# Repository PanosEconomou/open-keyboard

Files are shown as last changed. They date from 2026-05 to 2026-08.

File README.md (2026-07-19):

# open-keyboard

I want a cool keyboard, and if I am going to spend so much money on a good one that someone else makes why not spend even more money for a worse one that I make?

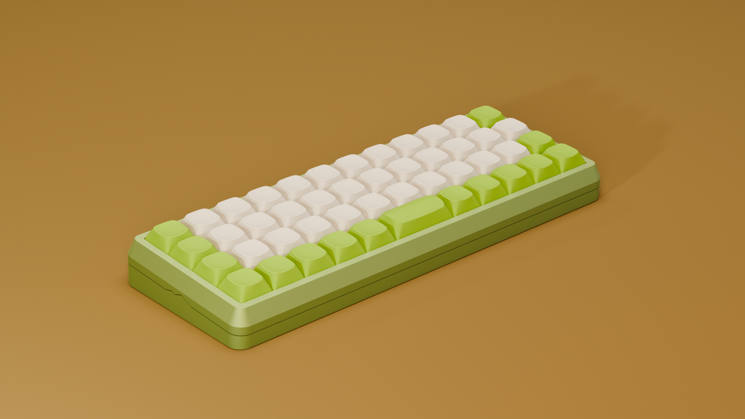
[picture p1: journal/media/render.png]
render


## Journal

There is a [journal](./journal/02-layout-framing.md) here somewhere that documents the process.

## Acknowledgements

This project uses or is inspired by a lot of open-source tools, projects, and generous people who documented their work. Thank you so much!

### Tools & Software
- [Keyboard Layout Editor](https://www.keyboard-layout-editor.com) — Ian Prest's layout design tool, used for every layout iteration
- [QMK Firmware](https://qmk.fm) — the open-source "Quantum Mechanical Keyboard" firmware
- [FreeCAD](https://www.freecad.org) — open-source CAD used for the case design
- [KiCad](https://www.kicad.org) — open-source EDA used for the schematic and PCB
- [Blender](https://www.blender.org) — used for the renders
- [Plate & Case Builder](http://builder.swillkb.com) — swillkb's tool for generating plates/cases from a layout

### Open-Source Projects & Libraries
- [cubiq/OPK](https://github.com/cubiq/OPK) — open keycap profile / library (included as a submodule)
- [CadQuery](https://github.com/CadQuery/cadquery) — Python-based parametric CAD used for keycap generation
- [ai03-2725/MX_V2](https://github.com/ai03-2725/MX_V2) — MX switch KiCad component library
- [ebastler/marbastlib](https://github.com/ebastler/marbastlib) — recent MX hotswap footprint library (the one I went with)
- [kiswitch/kiswitch](https://github.com/kiswitch/kiswitch) — switch footprint library
- [olkb/olkb_parts](https://github.com/olkb/olkb_parts) — OLKB's CAD parts, referenced for case design
- [adafruit/Adafruit-Feather-RP2040-PCB](https://github.com/adafruit/Adafruit-Feather-RP2040-PCB) — RP2040 reference design
- [Unified Daughterboard standard](https://unified-daughterboard.github.io) — daughterboard spec for the gasket-mount design
- [network2501/planck](https://github.com/network2501/planck) — long-press shift layout idea

### Guides & Articles
- [Ruiqi Mao's Keyboard PCB Guide](https://github.com/ruiqimao/keyboard-pcb-guide) — invaluable PCB walkthrough
- [The Planck Constant](http://thedarnedestthing.com/planck%20constant) — thoughtful write-up on Planck layout design
- [Evan Travers — 40% keyboard layouts](https://evantravers.com/articles/2019/04/20/community-post-40-keyboard-layouts/) — community layout roundup
- [Designing Keycaps for Fun and Profit (kbd.news)](https://kbd.news/Designing-Keycaps-for-Fun-and-Profit-1775.html) — PBS keycap creator's guide
- [RP2040 Hardware Design Guide (Raspberry Pi)](https://pip-assets.raspberrypi.com/categories/814-rp2040/documents/RP-008279-DS-1-hardware-design-with-rp2040.pdf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)
- [How to make your PCB hotswappable](https://www.reddit.com/r/MechanicalKeyboards/comments/5a399o/guide_how_to_make_your_pcb_hotswappable/)

### Community Threads & Inspiration
- [r/olkb](https://www.reddit.com/r/olkb/) and [r/MechanicalKeyboards](https://www.reddit.com/r/MechanicalKeyboards/wiki/customkeyboards/) — the wikis, guides, and countless threads
- [Detailed guide to making a custom keyboard](https://www.reddit.com/r/MechanicalKeyboards/comments/4l0p41/guide_detailed_guide_to_making_a_custom_keyboard/)
- [Default Planck layout thread](https://www.reddit.com/r/MechanicalKeyboards/comments/4vs3iz/this_is_the_default_planck_layout/) and [Planck PCB options](https://www.reddit.com/r/olkb/comments/rh9r3n/planck_pcb_options/)
- [40s keycaps — where to begin](https://www.reddit.com/r/MechanicalKeyboards/comments/dzamyl/40s_keycaps_where_to_begin/)
- [Gasket mounting discussion (geekhack)](https://geekhack.org/index.php?topic=101731.0) and [switch LED orientation (geekhack)](https://geekhack.org/index.php?topic=72713.0)
- [Planck PCB rev 6 (imgur)](https://imgur.com/a/planck-pcb-rev-6-8gn3UQs) — component-margin reference
- Geonix and YMDK Air 40 builds that got me started (linked in the README)

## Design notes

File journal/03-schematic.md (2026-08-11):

# Making the schematic

Having decided on the Planck layout there are a couple of things to consider a bout PCBs. 

- Solder or Hot swap. Turns out one doesn't have to solder switches in place if they don't want to by getting special pcbs with recepticles in them. Thing is because I haven't heard what different switches sound like and I would like to have mine be quiet, I might need to iterate on the swtitches so having to solder everything over and over again seems like a bummer. 
- Custom or kit. I would love to design one from scratch but this seems that it would take years to do hehehe. 
- Connectivity. I do want usb-C everything and given that custom keyboarding is dead as a hobby worldwide since before usb-c-ing the world it could be hard to find a nice USB. 
- Microcontroller. TURNS OUT YOU CAN DO THIS WITH A PRO MICRO?! That's awesome! I can write everything in an arduino IDE, or use qmk which apparently works.

[Here](https://www.reddit.com/r/olkb/comments/rh9r3n/planck_pcb_options/) is a thread of people talking about options for a planck pcb like 4 years ago. 
Also, [this](https://customkbd.com/collections/complete-kits/products/contra-40-keyboard-kit) seems to still be available as a kit, which is quite encouraging. I can use whatever microcontroller I want, but I would have to solder all the switches there. Here is another [similar option](https://kprepublic.com/collections/daisy-40/products/jj40-v1-5-40-custom-keyboard-pcb-similar-with-planck).

There is [this article](https://www.reddit.com/r/MechanicalKeyboards/comments/5a399o/guide_how_to_make_your_pcb_hotswappable/) on reddit 10 years ago that teaches you how to turn a pcb into hotswap.

Honestly the more I think about it, the easier it might be to design my own pcb and then send it to JLC or something to cut. Since I don't have to worry too much about the microconstroller, it might actually be just fine, plus apparently the switches can just be wired together in some matrix without any pullups or complicated stuff to figure out. I just have to be careful about how diodes are wired.
Here is a [guide](https://github.com/ruiqimao/keyboard-pcb-guide) which is 10 years old but it doesn't matter! 
Plus if I get the arduino itself, I won't even have to work out clocks and decoupling and all that stuff that I never really wanted to figure out.

You know what? Let's try it out!

## First Attempt

OK! Let's try this. We are going to use ki-cad which is open source, and apparently 10 years ago a bunch of people made the footprints needed for all the components for ki-cad. So this is great. 

There is a nice component library that I can use that is not that outdated right [here](https://github.com/ai03-2725/MX_V2). After some contemplating I decided not to include any space for LEDs. MX switches don't use LEDs anyway, and the way to do that would be to solder LEDs below them I don't really know what the best practices though are so I would like to get the basics down first.

There is a nice [yoututbe video](https://www.youtube.com/watch?v=fYNxG8RwpaE) that is relatively recent that explains some things with kicad.

Anyway it was honestly quite satisfying to get started with the keyboard switches themselves, so here they are.
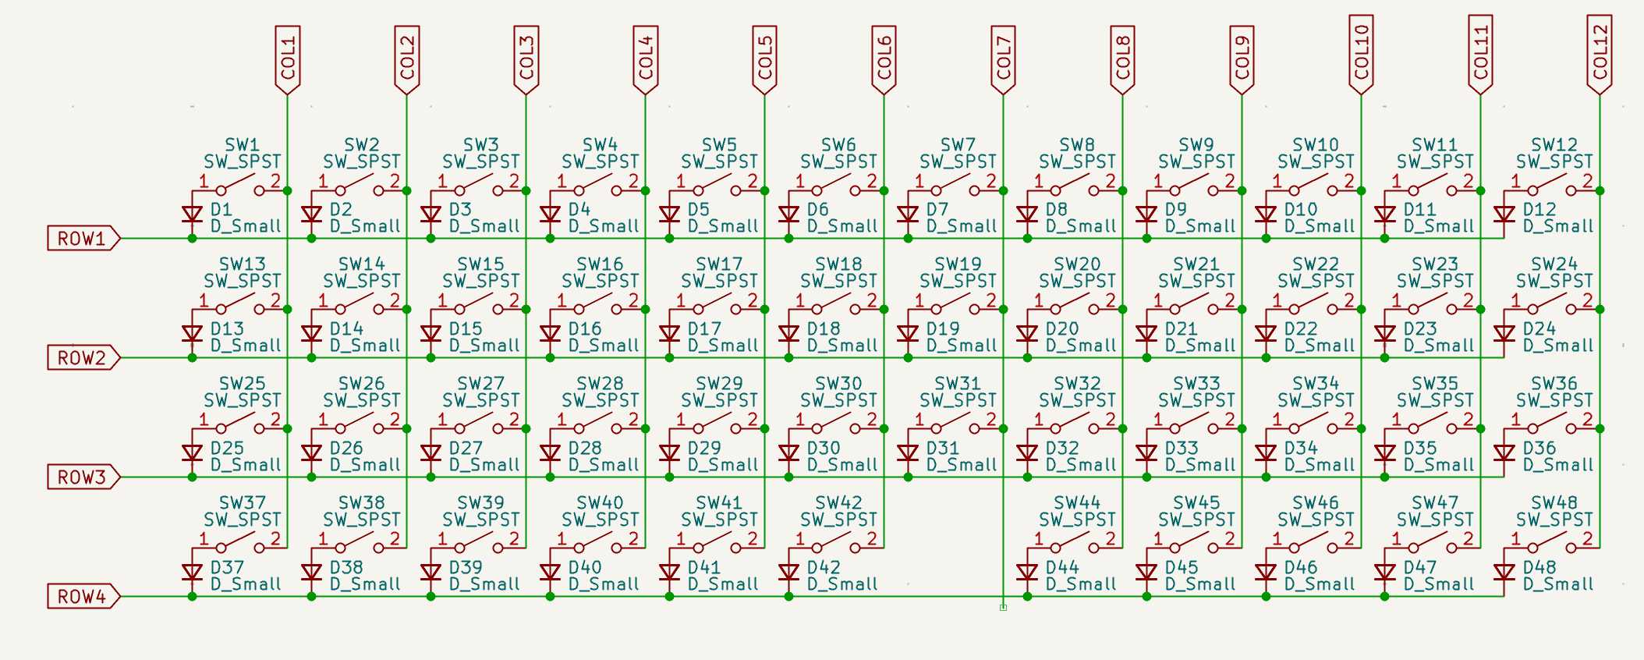
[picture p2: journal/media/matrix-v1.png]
Switch matrix


There is a "missing key" but this is because in our layout the spacebar takes two keys so we have $12\times 4 - 1 = 47$ keys which is a bit unsatisfying but in the future I might just do something like putting a space for the pcb to have the option to put two switcher OR 1 in different places.

## The microcontroller

Turns out that an arduino micro works wonders. But I am worried that if I don't solder my microcontroller in the board, then the keyboard would not be able to take much abuse. So we could simply recreate the arduino in the board! Luckily they provide all [schematics](https://store.arduino.cc/products/arduino-micro-without-headers) for free! They are all open source which I absurdly love.

The way we will do this is by stealing the microcontroller first which is the [ATMega32U4](https://www.microchip.com/en-us/product/atmega32u4) and reading the datasheet we can understand with dread that this is NOT OPEN SOURCE? WTF? While the arduino schematics are open source, this isn't, which is fine. 

After some looking around turns out that Raspberry Pi has developed an open hardware microcontroller the [RP2040](https://www.raspberrypi.com/products/rp2040/). I mean I guess it is not technically open hardware because no microcontroller has a nonpropriatary silicon layout or whatever. However, it has exhaustive documentation and all in good faith, plus is a crap ton faster than the ATMega, so we will use that!

There is a [hardware design guide](https://pip-assets.raspberrypi.com/categories/814-rp2040/documents/RP-008279-DS-1-hardware-design-with-rp2040.pdf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) for this chip which is particularly nice, and helps us not fuck up too hard with everything there. Thankfully thre is also a [youtubea](https://www.youtube.com/watch?v=swTL_IkvzjA) video that explains how to figure out the right width for certain routing and so on. 

## Connectivity

I mean I love USB-C so we will use it! The only real thing I need to keep in mind which I found about online is to use a protection circuit with a bunch of diodes that prevents surges in the data lines of USB.  

When it comes to connecting to the microcontroller we need to take special attention to impedance matching. The only way I understand this is through physics. If the wire of the USB has some impedance and your circuit suddenly has something else the wave will literally reflect or refract causing shockwaves and interference with the data. So it is important to add resistors as well as calibrate the DATA channels of the PCB accordingly so that the pulse travels without breaks.

The hardware design guide gives some extra information on that and how to achieve it. In particular they say that behind the data pins there MUST be just ground otherwise all hell will break loose and we will all die. 

There must be an electrostatic discharge protection circuit on the USB, which a lot of people use [USBLC6-2SC6](https://www.st.com/resource/en/datasheet/usblc6-2.pdf), typically you would need something larger, but I am actually going for small form factor. 

## Power

Technically speaking the RP2040 needs two power sources. 3.3V and 1V. Thankfully it has an onboard voltage regulator from 3.3V to 1V so we only need a regulator from the 5V of the USB-C down to 3.3V. The hardware design guide suggests to use the [NCP1117](https://www.onsemi.com/pdf/datasheet/ncp1117-d.pdf) which is simple to wire and can provide up to 1A which is definitely more than enough for our purposes. I mean we are not even driving LEDs but even if we were there is no reason to care.

The voltage regulator comes in two packages. DPAC which is large and SOT which is small. The only real  difference seems to be how they handle heat. I genuinely don't think that we will have any reason to wory about the heat a 3.3V regulator from 5V would produce for driving a SINGLE measely microcontroller, but just in case, I checked the specs. There is no way we will draw more than 500 mA at 5V and apparently people feel comfortably using SOT (the tiny version) at that. 

Another important consideration according to the schematics is to use decoupling capacitors. we basically want a 100nF capacitor between all ppower pins to be placed physical close to them. Basically the power supply creates so much magnetic field that if it starts oscillating widely it can literally affect the microcontroller. Adding a capacitor turns this into an LC circuit where the power supply fluctuations from induced currents are smoothed out, allowing the microcontroller to operate at a higher efficiency.  

**UPDATE**: Turns out an NCP1117 is old and fragile and big. And while fiddling with the PCB I found out that there is little space for it. So let's move onto a different one. This [reddit response](https://www.reddit.com/r/PrintedCircuitBoard/comments/1mns8ue/review_request_rp2040_number_pad_pcb/)has some great advice and great reasons not to use the NCP1117.

A good alternative is the [AP2112K-3.3TRG1](https://www.digikey.com/en/products/detail/diodes-incorporated/AP2112K-3-3TRG1/4470746), it is more modern, functions with much smaller external resistance, I can still use 0402 capacitors. So we will replace that on the schematics.

An extra consideration is how much capacitance to put. The datasheet says minimum 1u, so I will go with 10u. Everyone also uses bigger footprints for the regulator capacitors, so we can try and place 0603 there. 

## Crystal

Things are starting to get a bit scary. This is probably because I have the least experience with this, but it seems to be a finicky thing altogether. Basically we want to provide an oscillating voltage on our microprocessor in order for it to act as a clock. While it does have an internal crystal it is highly recommended by raspi to use an external one. They, in-fact gave us the specifications for the crystal they extensively tested and provided ample warning about testing a billion times if you change the crystal.

So, I will go with whatever they said, which is the [ABM8-272-T3](https://www.digikey.com/en/products/detail/abracon-llc/ABM8-272-T3/22472366). The only thing that we need to do in order to hook it up is to estimate the parasitic capacitance in order to make sure things work out. In particular the capacititance of the crystal should be tuned based on the overall stray capacitance of the pcb.

## Flash storage

So as far as I understand the rp2040 needs external storage to work. This is fine, they provide a list of supported external flash storage to hold the program, but what we will need is a way to tell both the microcotroller and the flash if it is time to store a program or spit it out. The hardware design guide uses a couple of exposed pins. I think it is better to use either a pushbutton, or a switch (probably a pushbutton is best tbh)

In fact my pushbutton ambitions were confirmed by looking at [raspi pico](https://learn.adafruit.com/adafruit-feather-rp2040-pico/pinouts#buttons-and-rst-pin-3084847) which uses a similar design. Perhaps we should get some inspiration from [its setup](https://github.com/adafruit/Adafruit-Feather-RP2040-PCB/blob/main/README.md) to design the keyboard's.

The flash storage they use is large and we will keep it that way because I have no idea how complicated I want the code to be yet. Plus they tested it so great! It is [W25Q128JVS](https://www.digikey.com/en/products/detail/winbond-electronics/W25Q128JVSIQ/5803943) and it has a relatively small footprint. Though if this seems an issue down the line, we can go for something with less memory. Speaking of footprint, reading the datasheet, the S at the end stands for SOIC which is pretty large as a package but much easier to solder. We will see at the end what matters most I guess. The other alternative is the P which is a 6x5mm WSON package that doesn't have exposed pins. 

The pushbuttons I want to use are [kmr2](https://www.littelfuse.com/products/switches/tactile-switches/kmr2) which appear to be a popular choice, and OH MAN they are satisfying and cute to press!

Here is the final version 1. 
Keyboard Schematic V1

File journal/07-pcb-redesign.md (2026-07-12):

# PCB Redesign

After realizing that I prefer gasket mounting one problem became clear: If the USB is mounted on top of the board, then it would move as the keyboard flexes when I type. That sounds horrible. People usually fix this by introducing daugher boards, that put the connectors in a different place than the main pcb and connect them via some sort of cable. Let's try and design something.

## Daugher Board

My original plan was to create a small usb daugher board, mount it on the case, and then use some kind of 4 pin connector to mount the usb signal to the main board. There are some standards even for these types of daughter boards, but honestly I quickly realized something. The original schematic is very compact. Honestly having a connector that will hit the USB port that will then have to pass under a couple of scanning signals in a 2-Board PCB might not be the wisest option to consider. So thne I thought, why not kill two birds with one stone by moving all the active parts in the "daughter board," including the microcontroller and so on and then connect the keyboard matrix with some sort of ffc cable like a laptop keyboard?

This way we can have a low profile board, with short USB connection and everything else, accompanied by a simple keyboard matrix that lies on the gaskets. Let's try to build that.

## FFC Connectors

While looking things up I found out [this guide](https://vistarelectronics.com/how-to-select-the-right-fpc-ffc-connector/) for how to pick the right FFC type connector for the job, and [this one](https://www.digikey.gr/en/blog/ffc-fpc-connector-and-cable-compatibility-basics) for how to pick the right cable. So here is the verdict:

1. **Pitch:** 0.5 mm. It's the modern standard I have no reason to use something crazy, plus JLC can do this NO PROBLEM. Why make it harder for them?
2. **Actuator Type:** ZIF (Zero input force). This is the one that actively clasps the cable in place. It's much better since I will probably clasp and unclasp it a bunch. Plus there are some really low profile ZIF connectors anyway so I am not that concerned. 
3. **Contact Direction:** Bottom. I mean it gives lower profile overall, idk it sounds so much more reasonable than top. This is also the most common choice for connecting daughterboards and whatnot.

Let's assemble some candidates
- [5051101892](https://jlcpcb.com/partdetail/MOLEX-5051101892/C3036269)
- [AFC01-S18FCA-00](https://jlcpcb.com/partdetail/JUSHUO-AFC01_S18FCA00/C262666)
- [XW05200-18](https://jlcpcb.com/partdetail/MINTRON-XW0520018/C376063)
- [TF31-18S-0.5SH(800)](https://jlcpcb.com/partdetail/HRS_Hirose-TF31_18S_0_5SH_800/C3168422) (SELECTED)

Out of these 4 the most trusted companies are Molex (the first) and Hirose (the last). The last one is 1.75mm in thickness while the first one is 1.9mm in thickness. In addition the last one allows for an FFC design with a little lip so that it withstands more horizontal force than the first. I hope its vertical force performance is just as good, but it's worth checking before I commit. 

The issues with these 4 is that 18 pins is quite long, so the whole thing will not fit between the hotswap sockets on the bottom part of the matrix. So we would probably want to aim for a more compact cable and connector.

## Track width settings 

Now that I get to redesign the board I think I should pay more attention to things like track widths and whatnot. Before I just almost took things to be defaults, but honestly this time I might just use smaller ones. Like everything in say raspi pico has signal lines to be smaller than 1mm and I was kind of afraid to figure it out. Let's try something new now! 

Kicad has a [guide](https://docs.oshpark.com/design-tools/kicad/kicad-design-rules/) that talks about what kind of DRC is preferrable for this type of boards and how to figure out in one's particular case. I can use that. But I can't trust it. It needs to be specific to the RP2040.

The hardware design guide for the RP2040 does not say much about track widht, so we can check the Raspi Zero to see what's up. They have many differnet trace widths, but honestly for GPIO Pins the trace widths are roughly 0.2mm with 0.2 mm clearance at the DRC. I checked to see in JLC's manufacturing guidelines and it's well within limits. Actually, let's try 0.15 mm width and clearance because the pins in the RP2040 are so freaking dense, I am having issues hahahaa. Here are [JLC Manufacturing capabilities](https://jlcpcb.com/capabilities/Capabilities) 

For the QSPI pins though, it matters more. Impedance matching plays a crucial role there, but placing the flash memory close to the rp2040 kinda makes this less of a problem. [People recommend](https://pcbartists.com/design/embedded/rp2040-pcb-design/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) a trace of around 0.15 mm with 0.2 mm clearance where none of the traces are more then 1 inch in length and the clock trace should be the longest. Another important consideration is to use a solid ground plane to connect the flash and microcontroller grounds.  

[This article](https://www.allpcb.com/blog/pcb-knowledge/the-ultimate-guide-to-pcb-trace-width-for-beginners.html) gives a cool introduction to figuring out how to select the correct trace dimensions. So we can use it for power. The maximum current we are ever expecting to draw would be around 40mA. In terms of temperature the blog suggests to account for 10 degrees above room temperature, so might as well do that. The thing is that the power consumption is so low, that whatever trace width I pick it won't matter. So might as well design it for 1A peak consumption just in case in the future I edit this to add a couple of LEDs. KiCad's calculator gives me a 0.3 mm trace width for these specifications, and 0.2 mm gaps. 

Now the hardest one to do is USB. We can use a calculator that exists in KiCad such that we achieve 90 Ω resistance. This is the **Transmision Line Calculator** I entered all the parameters of the board and I found out that it can't be set to 90 Ohms for a 2-layer board because the thickness is too small. A quick google search shows that we can't actually achieve USBC high speed at a 2-layer board anyway, so it is fine to go 20% over as we will still retain full speed. Doing this we get a 0.25 mm Width with 0.15 mm clearance at roughly 10 mm length for 115.5 Ω differential resistance. Actually at the end I ended up using 0.65 mm with 0.15 clearance which has 93 Ohms differential impedance on my stackup which is pretty cool. 

## Bending and angles

Another interesting thing is that apparently pcb cnc machines hate making sharp angles, even though in my understanding everything is a sharp angle in most PCBs I have seen. Let's explore what kind of angles we can put here. 

## New Buttons

I decided that the old buttons were too big and clunky and honestly there is no reason to make them accessible outside the keyboard now, so mught as well try for something smaller that can fit in a tinier board. Here is a new one from some known company [SKRPAME010](https://jlcpcb.com/partdetail/ALPSALPINE-SKRPAME010/C19724063).

## New flash

Here is a picture with the full flash and kind of the best routing I could do

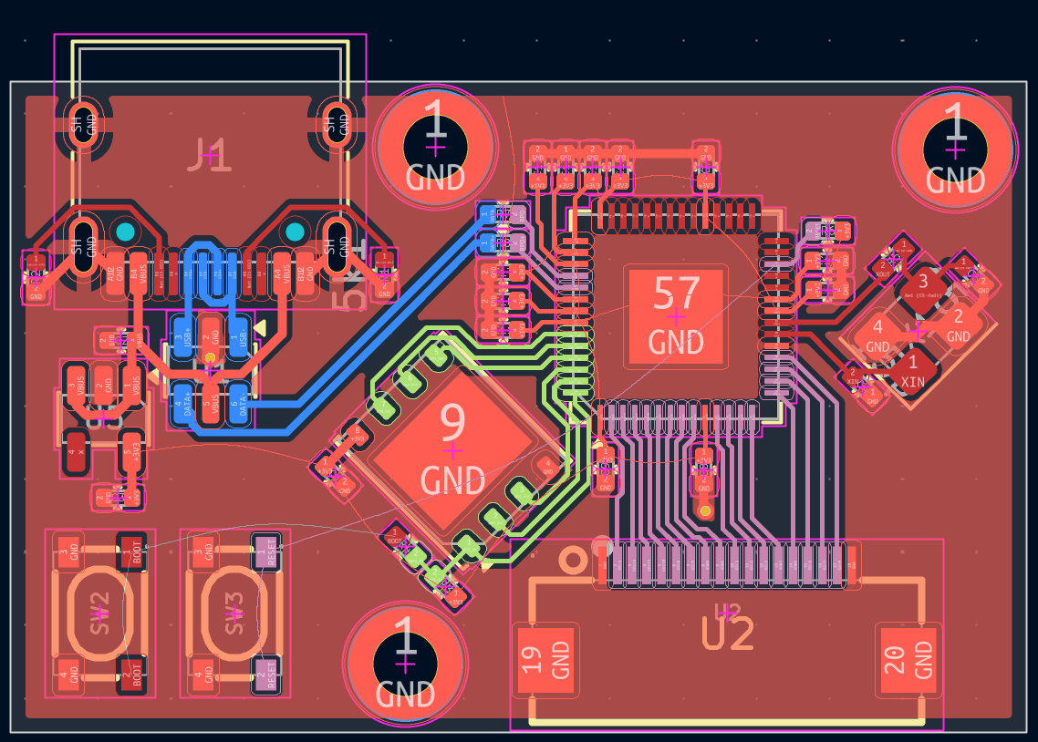
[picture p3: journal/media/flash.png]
flash


The component at the center with thermal pad 9 is the flash memory. It's 2MB and honestly there is no keyboard firmware that will be 16MB. It also causes the whole board to be shifted a bit awkwardly, so we will change that. Raspberry Pi Pico uses a [W25Q16JVUXIQ](https://jlcpcb.com/partdetail/WinbondElec-W25Q16JVUXIQ/C2843335) which is a 2MB chip and honestly is still overkill in terms of capacity, but it comes in a 2x3 mm package!

## Test Points

In my layout there is a bit of free space to play with, so perhaps it is the perfect opportunity to add some test points! Header pins ended up looking massive so I really only have space for two pairs of two. One should clearly be the 3.3V net and ground so that I check that power is working properly and have a reference for the rp2040 io. Then I was thinking of exposing some more GPIO pins. Looking at the datasheet, pins GPIO26 and GPIO27 are not only also ADC but they also form an I2C bus. So these are the obvious choice here for test points. 

## PCB Mascot

An equally or perhaps more important aspect of this PCB is the silkscreen design at the back. I think that since the keyboard is called pankeyk, a little cute pancake mascot would be so fun to put! Or like a little pan flipping a keycap as if it is a pacake. I'll try to design something in inkscape.

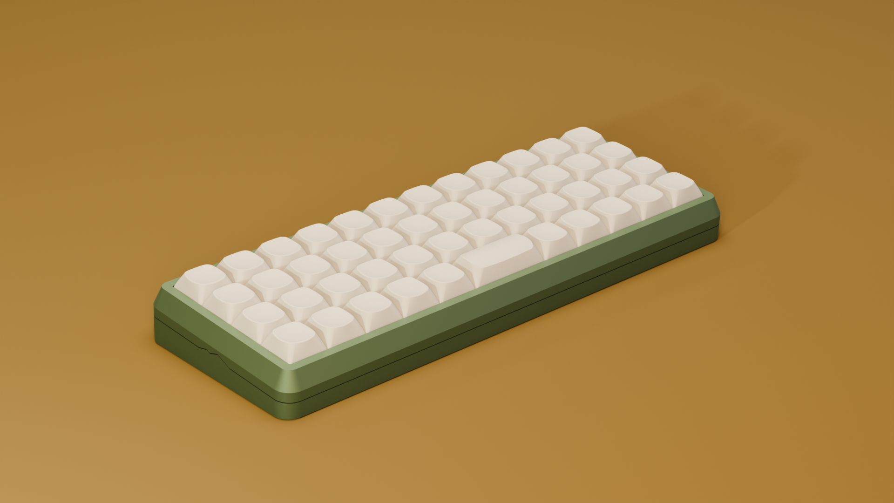
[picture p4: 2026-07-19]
case/gasket-mount-v1/render/iso_green_base.png

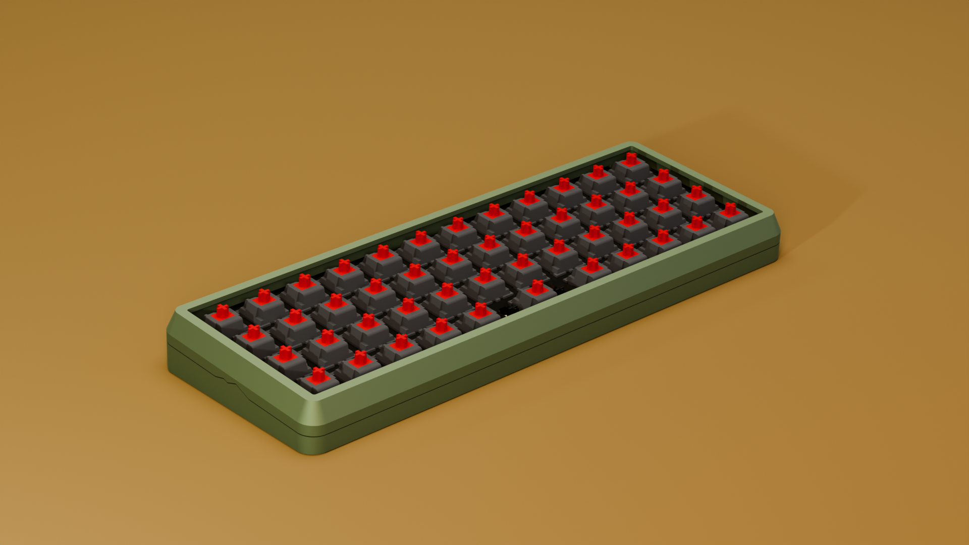
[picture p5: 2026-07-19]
case/gasket-mount-v1/render/iso_green_base_no_keycaps.png

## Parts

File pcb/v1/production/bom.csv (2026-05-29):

Designator | Footprint | Quantity | Value | LCSC Part #
C1, C11, C12, C14, C15, C16, C17, C6, C7, C8, C9 | 0402 | 11 | 100n | 0402B104J160CT
C10, C13, C2, C3 | 0402 | 4 | 1u | GRM155Z71A105KE01D
C4, C5 | 0402 | 2 | 15p | GRM1555C1H150FA01D
D1, D10, D11, D12, D13, D14, D15, D16, D17, D18, D19, D2, D20, D21, D22, D23, D24, D25, D26, D27, D28, D29, D3, D30, D31, D32, D33, D34, D35, D36, D37, D38, D39, D4, D40, D41, D42, D43, D44, D45, D46, D47, D5, D6, D7, D8, D9 | D_SOD-323 | 47 | 1N4148WS | 1N4148WS
J1 | USB_C_Receptacle_HRO_TYPE-C-31-M-12 | 1 | USB_C_Receptacle_USB2.0_16P | TYPE-C-31-M-12
MX1, MX10, MX11, MX12, MX13, MX14, MX15, MX16, MX17, MX18, MX19, MX2, MX20, MX21, MX22, MX23, MX24, MX25, MX26, MX27, MX28, MX29, MX3, MX30, MX31, MX32, MX33, MX34, MX35, MX36, MX37, MX38, MX39, MX4, MX40, MX41, MX42, MX43, MX44, MX45, MX46, MX47, MX5, MX6, MX7, MX8, MX9 | SW_MX_HS_CPG151101S11_1u | 47 | MX_SW_HS | CPG151101S11-2
R1, R2 | 0402 | 2 | 5k1 | CRCW04025K10JNED
R3, R6 | 0402 | 2 | 10k | CRCW040210K0FKEDC
R4, R5 | 0402 | 2 | 1k | CRCW04021K00FKED
R7, R8 | 0402 | 2 | 27.4 | CRCW040227R0FKED
SW1, SW2 | SW_SPST_TL3342 | 2 | SW_Push | TL3342F160QG
U1 | SOT-23-6 | 1 | USBLC6-2SC6 | USBLC6-2SC6
U3 | WSON-8-1EP_6x5mm_P1.27mm_EP3.4x4.3mm | 1 | W25Q128JVP | W25Q128JVP
U4 | QFN-56-1EP_7x7mm_P0.4mm_EP3.2x3.2mm | 1 | RP2040 | RP2040
U5 | SOT-23-5 | 1 | AP2112K-3.3 | AP2112K-3.3
X1 | Crystal_SMD_Abracon_ABM8G-4Pin_3.2x2.5mm | 1 | ABM8-272-T3 | ABM8-272-T3

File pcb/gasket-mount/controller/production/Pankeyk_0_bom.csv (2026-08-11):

Designator | Footprint | Quantity | Value | LCSC Part #
C10, C13 | 0402 | 2 | 1u | C52923
C11, C12, C14, C15, C16, C17, C18, C6, C7, C8, C9 | 0402 | 11 | 100n | C1525
C2, C3 | 0603 | 2 | 10u | C96446
C4, C5 | 0402 | 2 | 15p | C1548
J1 | USB_C_Receptacle_HRO_TYPE-C-31-M-12 | 1 | TYPE-C-31-M-12 | TYPE-C-31-M-12
R1, R2 | 0402 | 2 | 5.1k | C25905
R10, R6 | 0402 | 2 | 10k | C25744
R5, R9 | 0402 | 2 | 1k | C11702
R7, R8 | 0402 | 2 | 33 | C25105
SW1, SW2 | KEY-SMD_4P-L4.2-W3.2-P2.20-LS4.6 | 2 | SKRPAME010 | C19724063
U1 | SOT-23-6 | 1 | USBLC6-2SC6 | USBLC6-2SC6
U2 | FPC-SMD_18P-P0.50_TF31-18S-0.5SH-800 | 1 | TF31-18S-0.5SH(800)
U4 | QFN-56-1EP_7x7mm_P0.4mm_EP3.2x3.2mm | 1 | RP2040 | RP2040
U5 | SOT-23-5 | 1 | AP2112K-3.3 | AP2112K-3.3
U6 | USON-8_L3.0-W2.0-P0.50-BL-EP | 1 | W25Q16JVUXIQ | C2843335
X1 | Crystal_SMD_Abracon_ABM8G-4Pin_3.2x2.5mm | 1 | ABM8-272-T3 | ABM8-272-T3

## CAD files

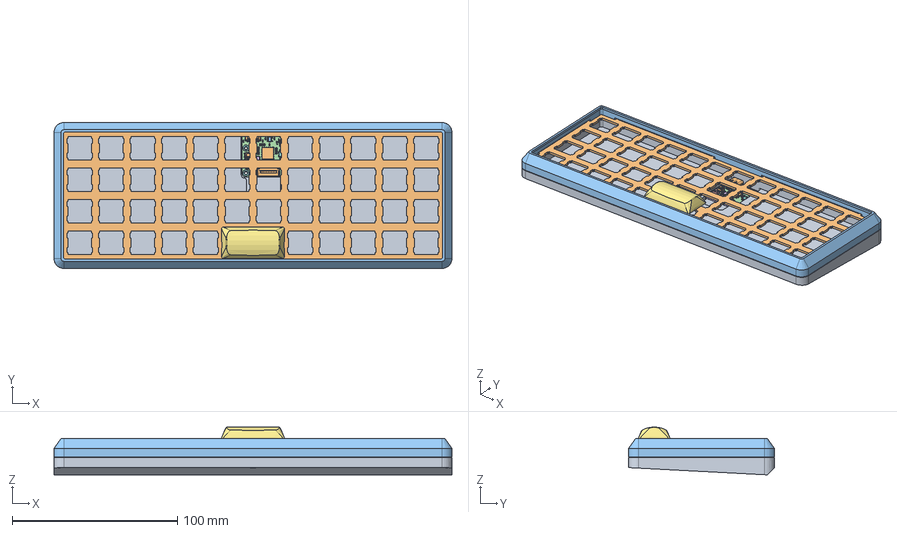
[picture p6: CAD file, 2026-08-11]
case/gasket-mount-v1/gasket-mount-v1.FCStd
240.6 x 88.2 x 28.9 mm
bottom
plate
top
gaskets
C_0402_1005Metric
R_0402_1005Metric
R_0402_1005Metric002
R_0402_1005Metric004
C_0402_1005Metric002
SOT-23-5
C_0402_1005Metric004
C_0402_1005Metric006
C_0402_1005Metric008
C_0402_1005Metric010
Crystal_SMD_Abracon_ABM8G-4Pin_3.2x2.5mm
R_0402_1005Metric006
TF31-18S-0_5SH-198390.PRT
C_0402_1005Metric012
C_0402_1005Metric014
R_0402_1005Metric008
R_0402_1005Metric010
C_0402_1005Metric016
R_0402_1005Metric012
C_0402_1005Metric018
QFN-56-1EP_7x7mm_P0.4mm_EP3.2x3.2mm
C_0402_1005Metric020
C_0402_1005Metric022
SOT-23-6
C_0402_1005Metric024
C_0402_1005Metric026
C_0402_1005Metric028
USB_C_Receptacle_16P_TopMnt_Horizontal_GCT_USB4105-xx-A
C_0402_1005Metric030
C_0402_1005Metric032
R_0402_1005Metric014
controller_copper
controller_pad
controller_via
controller_silkscreen
controller_silkscreen001
controller_soldermask
controller_soldermask001
controller_PCB
2u

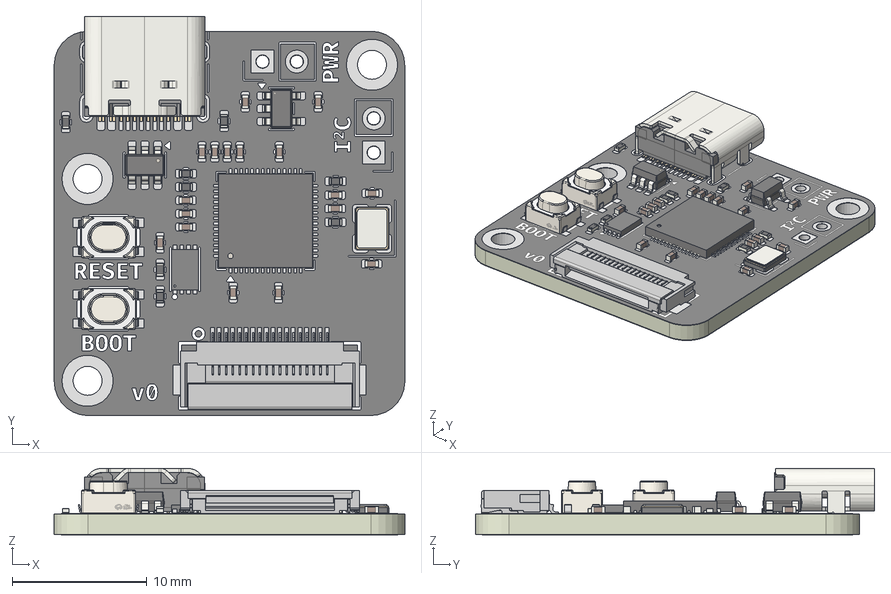
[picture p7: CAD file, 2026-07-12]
case/parts/board/controller.step
26.0 x 29.6 x 4.98 mm
C_0402_1005Metric x 17
R_0402_1005Metric x 8
SOT-23-5
Crystal_SMD_Abracon_ABM8G-4Pin_3.2x2.5mm
TF31-18S-0_5SH-198390.PRT
QFN-56-1EP_7x7mm_P0.4mm_EP3.2x3.2mm
SOT-23-6
USB_C_Receptacle_16P_TopMnt_Horizontal_GCT_USB4105-xx-A
controller_copper
controller_pad
controller_via
controller_silkscreen x 2
controller_soldermask x 2
controller_PCB

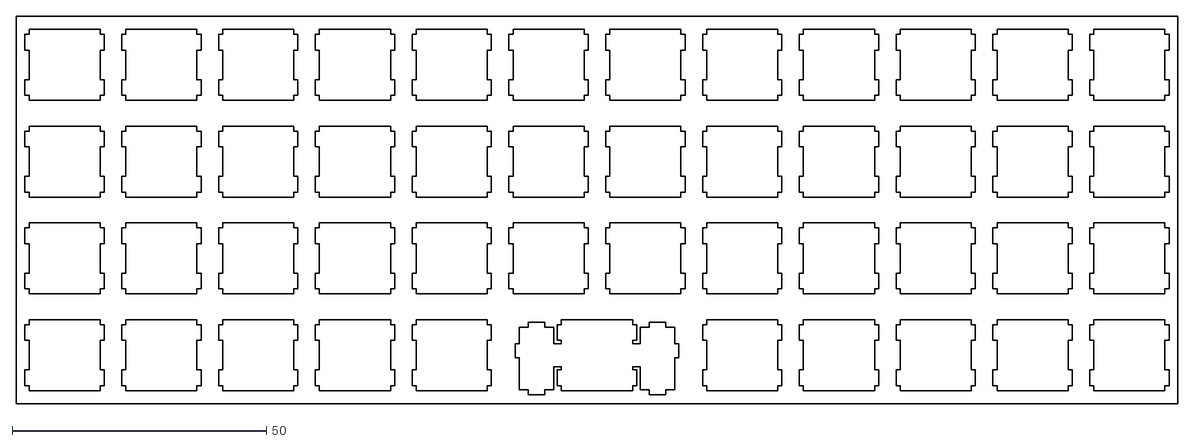
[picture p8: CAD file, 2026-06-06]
case/parts/plate/bare-plate-sketch.dxf
228.6 x 76.2

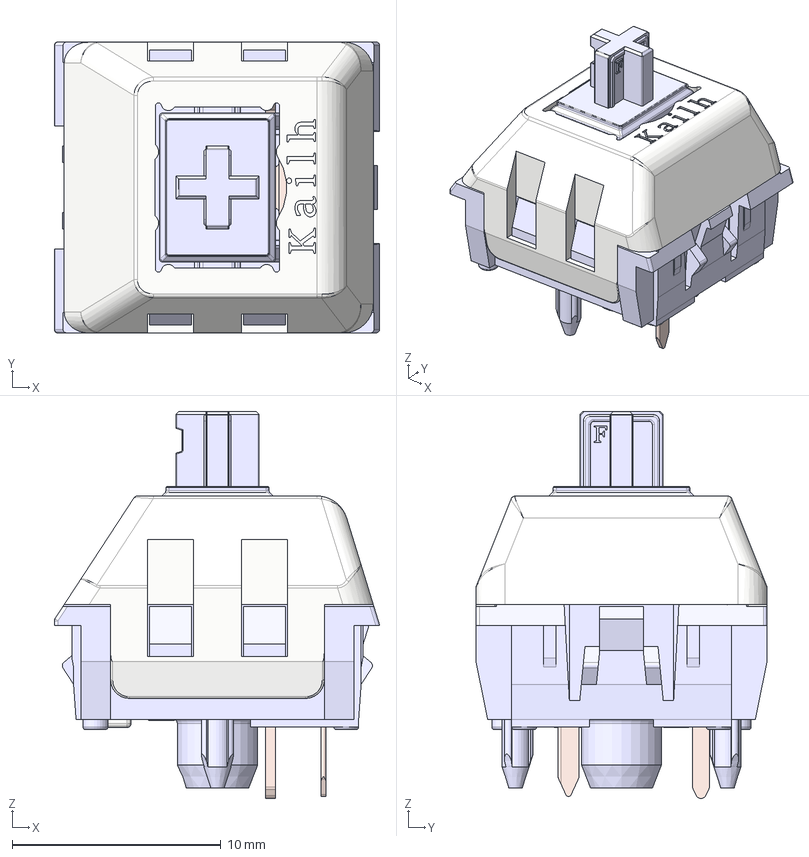
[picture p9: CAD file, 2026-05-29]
case/parts/switch/switch.step
15.6 x 14.0 x 18.5 mm
Housing
ThickContact
SpringContact
Stem
Lid

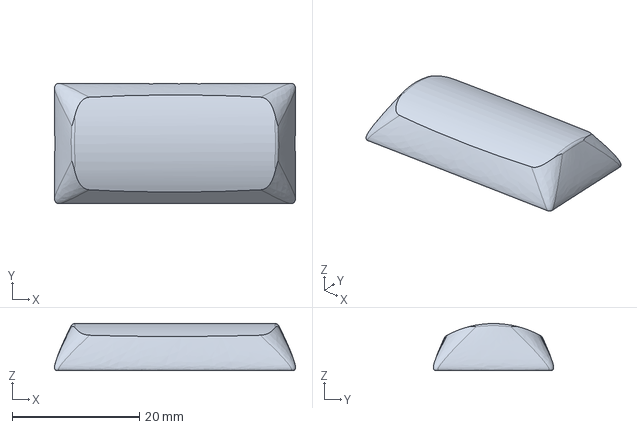
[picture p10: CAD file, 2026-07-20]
keycaps/keycap_2u.step
37.9 x 18.9 x 7.40 mm

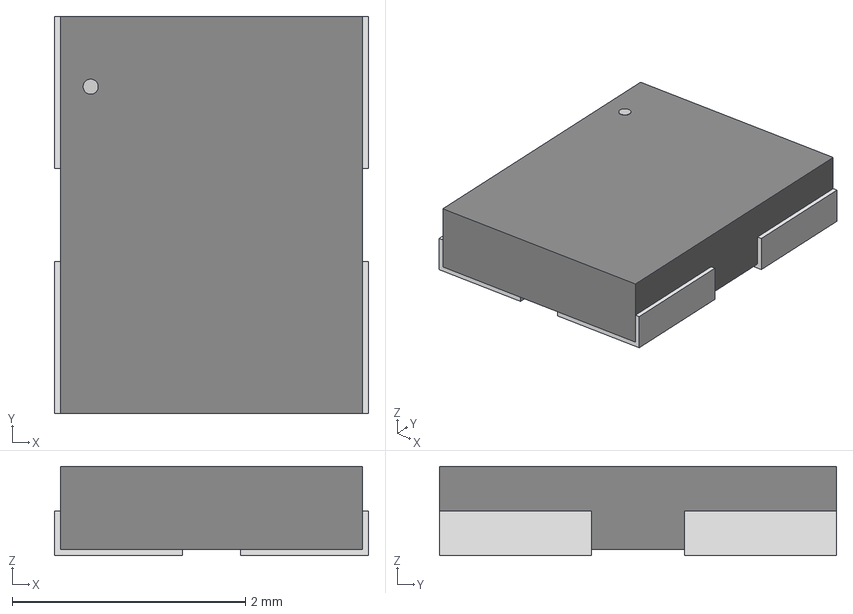
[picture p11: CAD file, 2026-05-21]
pcb/component-libraries/ABM8_272_T3/ABM8-272-T3_ABR.step
2.69 x 3.40 x 0.765 mm

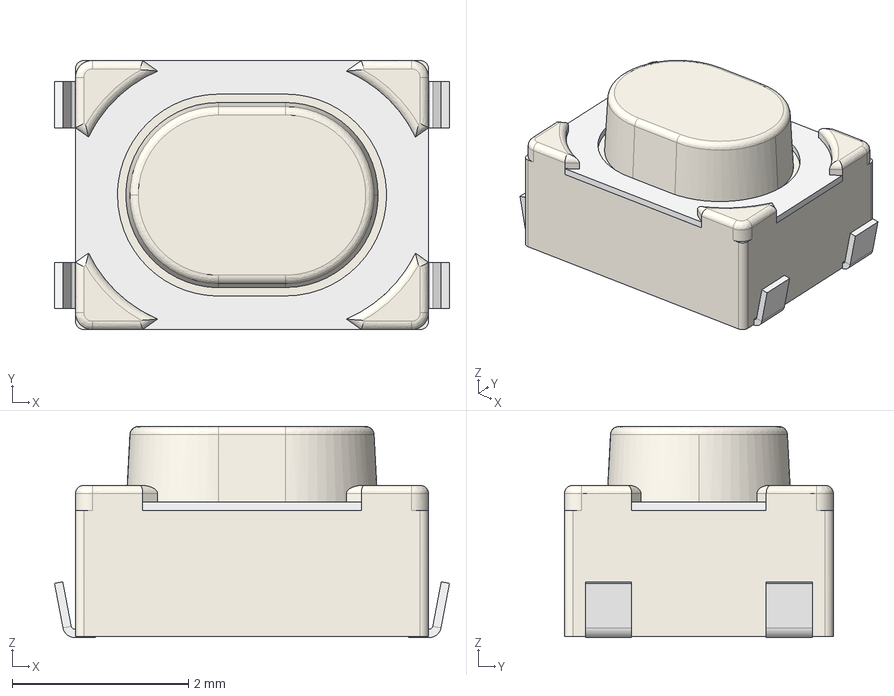
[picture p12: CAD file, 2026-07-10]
pcb/gasket-mount/controller/EASYEDA_MODELS/KEY-SMD_4P-L4.2-W3.2-H2.5-LS4.6-P2.2.step
4.48 x 3.05 x 2.39 mm

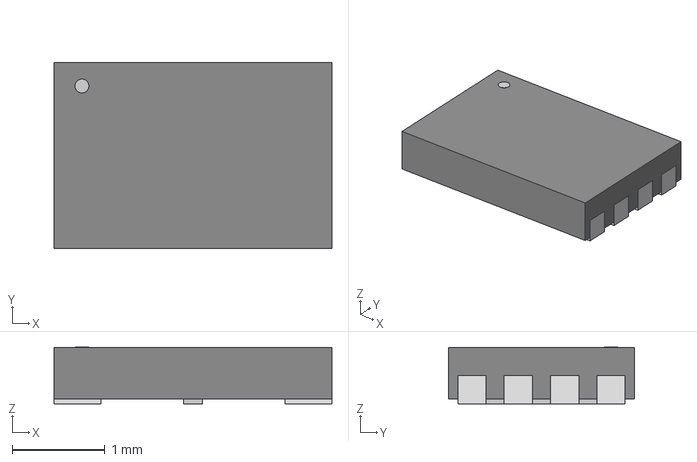
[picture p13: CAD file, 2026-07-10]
pcb/gasket-mount/controller/EasyEDA_Step/W25Q16JVUXIQ_WIN.step
3.00 x 2.01 x 0.612 mm

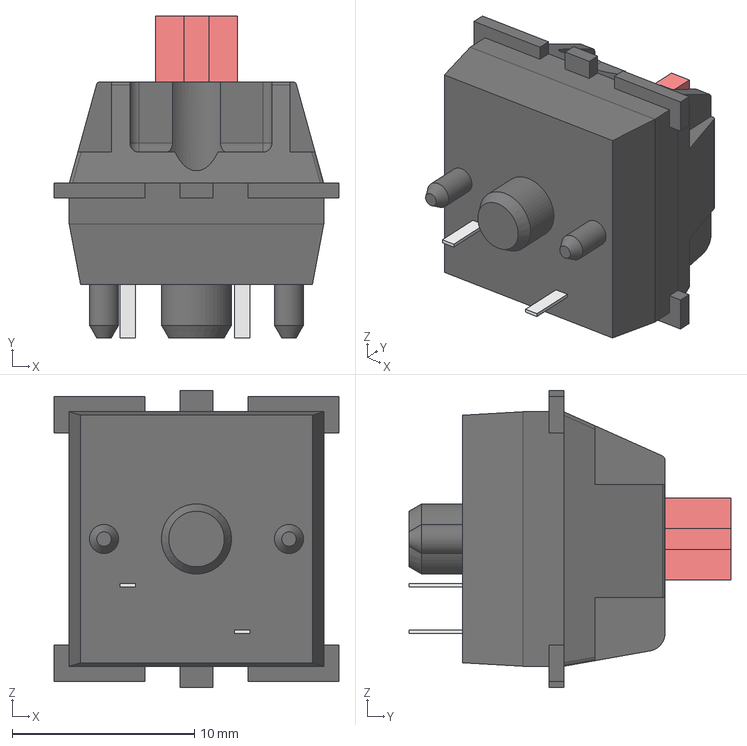
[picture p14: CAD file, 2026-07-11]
pcb/gasket-mount/matrix/EasyEDA_Step/switch.step
15.6 x 17.7 x 16.3 mm

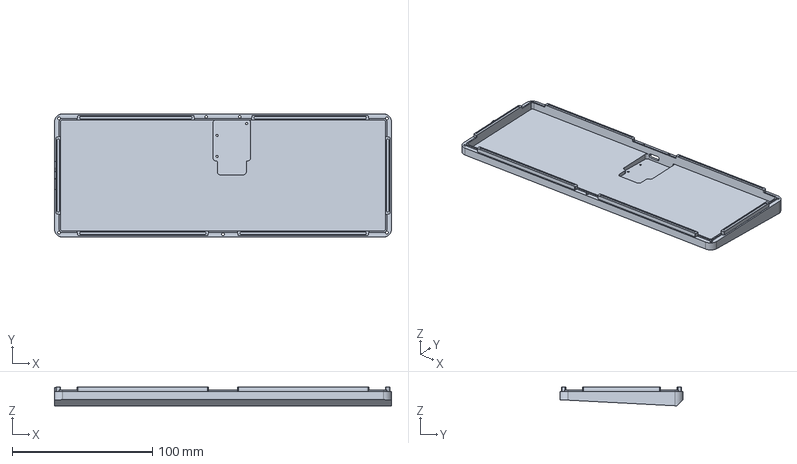
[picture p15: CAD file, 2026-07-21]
case/gasket-mount-v1/gasket-mount-v1-bottom.step
240.3 x 87.9 x 13.4 mm

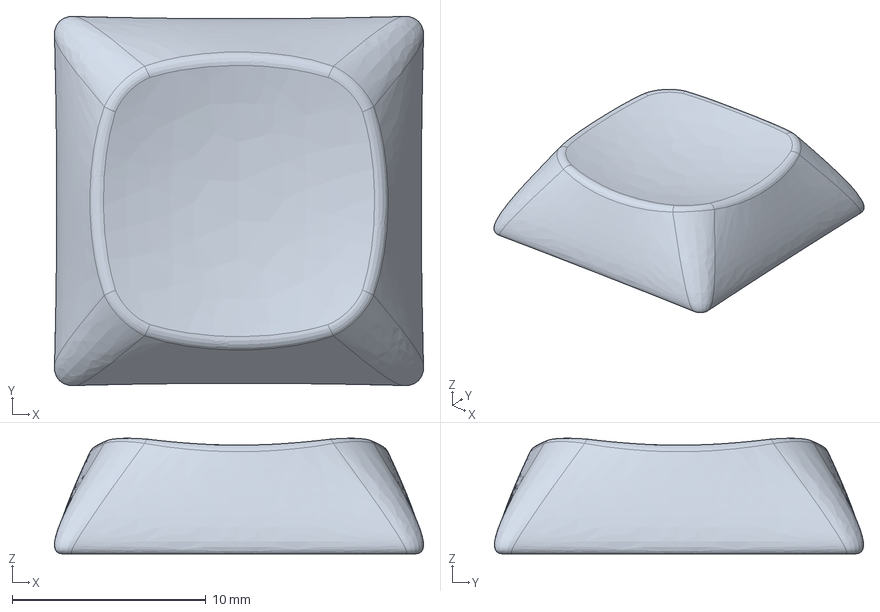
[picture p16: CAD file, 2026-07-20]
keycaps/keycap_1u.step
19.0 x 19.0 x 5.96 mm

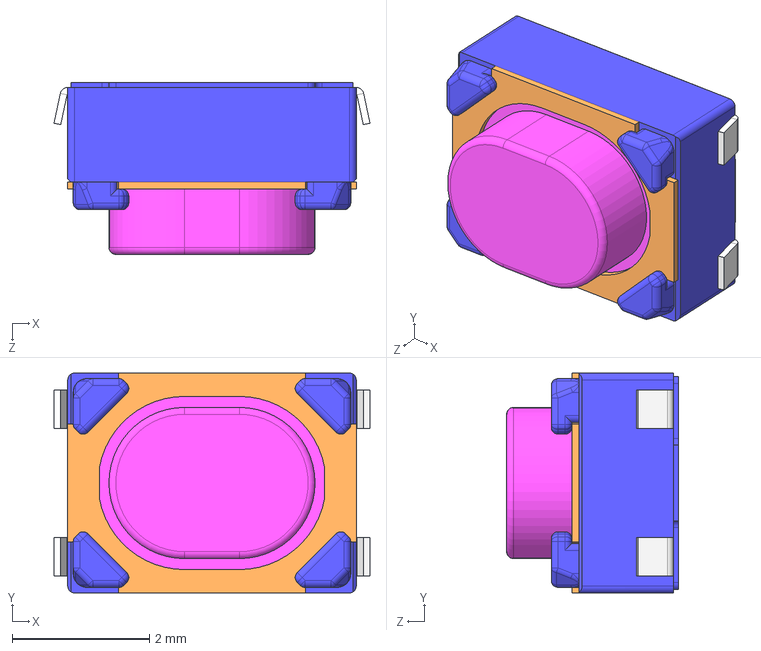
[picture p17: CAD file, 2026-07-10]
pcb/gasket-mount/controller/EasyEDA_Step/SKRPAB.STEP
4.60 x 3.20 x 2.50 mm

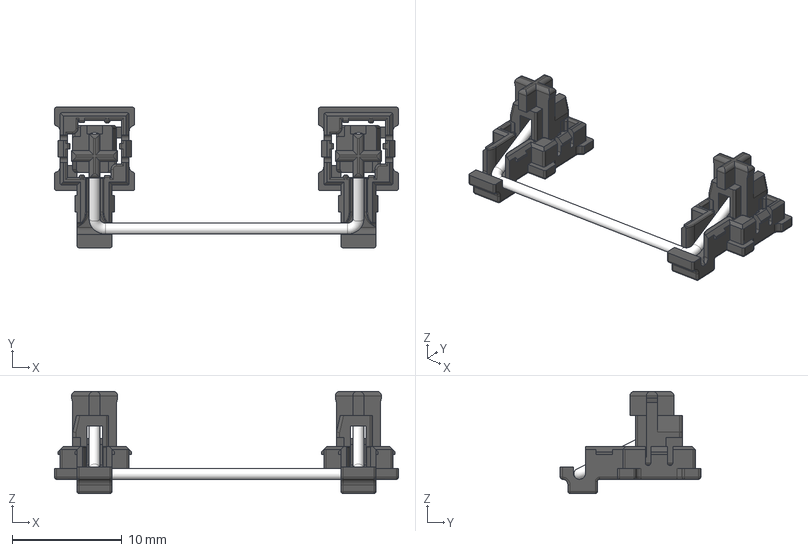
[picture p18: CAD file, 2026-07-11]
pcb/gasket-mount/matrix/EasyEDA_Step/stabilizer_2u.step
31.3 x 12.8 x 9.30 mm
body_l
stem_l
body_r
stem_r
wire_2u

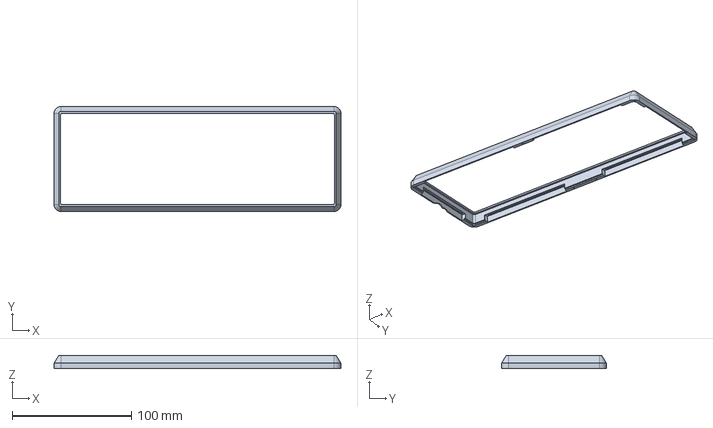
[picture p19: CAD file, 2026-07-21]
case/gasket-mount-v1/gasket-mount-v1-top.step
240.3 x 87.9 x 11.0 mm

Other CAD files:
pcb/gasket-mount/matrix/EasyEDA_Step/TF31-18S-0.5SH_800_.step
case/gasket-mount-v0/exports/gasket-mount-keyboard-bottom-plate.step
case/gasket-mount-v0/gasket-mount-keyboard.FCStd
case/gasket-mount-v0/exports/gasket-mount-keyboard-top-plate.step
case/gasket-mount-v0/render/Scene.blend
case/gasket-mount-v1/render/blenderer.blend

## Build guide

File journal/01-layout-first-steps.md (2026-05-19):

# Customizing the layout

The first and most important job of any keyboard, I am told, is to figure out the layout. It's awesome that I get to choose it myself. Here are some considerations:

1. **Tiny vs Normal:** I never really wanted a big keyboard, but I think a tiny keyboard is cute! I really want to check things out at the 40% regions of the keyboard nieche. 
Anyway since we're making everything from scratch, finding parts shouldn't really be an issue.
2. **Ortho vs Staggered:** While I am still learning how to consistently type properly perhaps having an ortho layout would be so cool, I also feel like doing this project would give me incentice to really learn how to type with such a keyboard. 
tbh, my computer really is unusable by anyone other than me, and I am handicapped when I go visit other people's computers anyway, so might as well transmit this issue in my keyboard too. 

## Designing the layout
I heard [keyboard-layout-editor](https://www.keyboard-layout-editor.com) is a good place to build a layout from scratch in most standard key arrangements or whatever that's called. We can also try to use keyd to implement the layout or a close approximation to my laptop keyboard to try and get used to it or optimize it along the process. 

[Planck](https://www.reddit.com/r/MechanicalKeyboards/comments/4vs3iz/this_is_the_default_planck_layout/) is a commonly used layout for 40% ortholinear keyboards which is the hard choice in both of my considerations above, but we can see where we can go from there.
The main plus about it is that it has two switches for going up and down layers along with other modifiers which are located right next to the spacebar in a natural position of the thumbs to rest. Here it is 

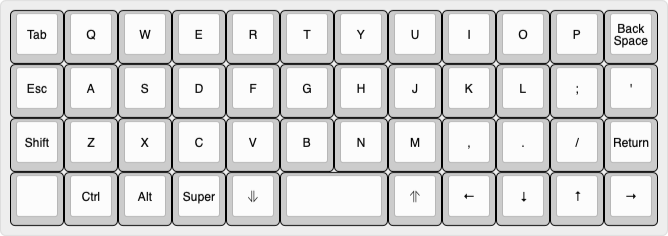
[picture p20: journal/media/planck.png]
default planck layout


We can iterate on this a bit. This was my first attempt.

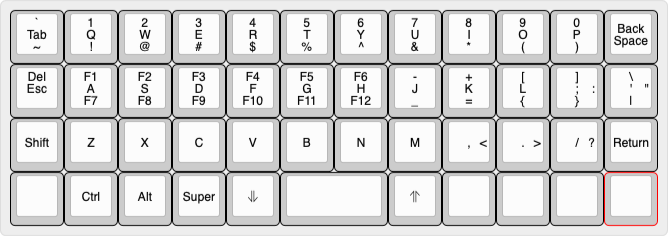
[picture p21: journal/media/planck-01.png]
default planck layout


It is not bad, and it's getting me quite excited. However, there seems to be a key issue. Learning how to type properly I learned To rely on the right shift which is now replaced by a return button which honestly isn't in the best position for me. Here are some ideas to fix that

1. Add an extra column of keys at the right end. 
This is not ideal. The whole point of the planck layout was to not have to extend a finger more than one key length. However, it might be a welcome compromise in order to return a home row return key. Yet the keyboard would no longer be symmetric which kind throws me off. 
2. Rework the apostrophy key position. Honestly it is the most annoying key to type by far, and it took me so much time to learn how to do it wihtout lifting my hand off the keyboard. However if we place it somewhere else we might be able to move the return key in its place and have the shift reclaim its original place. 
3. Another solution I found [here](https://github.com/network2501/planck) is to make shift keys long press. I never really through about that, but this makes perfect sense. I never type a shift key if it's not long press. That changes the home row enter key, but honestly I am not as mad about that as not having a right shift. 

In addition, the original Planck layout has a bunch of arrow keys, that I would really like to move to the home row instead. I am already comfortable with using HJKL for navigation so maybe it won't be such an issue. Plus, I move around with my mod key anyway on my workspace. 

Summary of Issues:

1. No right shift.
2. Enter is awkward.
3. \ for latex would be a pain to type as constantly as needed.
4. No real themeing for different functions. 
5. I have a bunch of SUPER + NON_ALPHA KEY mods that need to work while I am pressing other modifiers.

The rest of the keys look fine I guess. However, there is this [super nice article](http://thedarnedestthing.com/planck%20constant) about setting up a planck layout. I like the idea of using two spacebar keys that re modified depending on some modifier key. 

Also here is a [bunch of people's 4x12 layouts](https://evantravers.com/articles/2019/04/20/community-post-40-keyboard-layouts/)

Finally this has some nice things to [keep in mind](https://www.keyboard-layout-editor.com/#/gists/d06425aaccaef71cf3d0ffbc0e2042ba) while designing a custom 40% keyboard. I really like the idea of having a themed layout so maybe we can try and do that next. At some point I would like to optimize for latex and whatnot, so it would be nice to find out what the right balance for familiarity and ease of use would be.  
I found this funny [thread](https://www.reddit.com/r/MechanicalKeyboards/comments/5xp9h4/help_improve_typing_symbols_on_planck/) that suggests this [keymap](https://esinc.net/happyfamily/keymap.c) for a latex optimized layout.

There is this open source software [quantum mechanical keyboard](https://qmk.fm) that apparently has many layouts already implemented. Though they don't seem to be that crazy.

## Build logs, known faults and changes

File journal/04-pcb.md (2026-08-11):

# PCB

Now that we have a schematic time to convert it to a PCB at least in the computer. Thankfully kicad has a bunch of the footprints here, so there is no reason to worry too much. Anyway this pcb will be only a test of the connections as the overall shape will be determined by the case that we will design later in cad.  

## Switches

An important consideration are the footprints. There are open source libraries that can be used to provide MX hotswap footprints but A LOT of them are outdated. [Here](https://github.com/ebastler/marbastlib) is a relatively recent one, i.e. open source but 2-3 years ago.

Another one recommended is [Kiswitch](https://github.com/kiswitch/kiswitch), but it's updated 5 years ago, and I am not really sure. Let's go with the first one.

One decision we need to make is that there seem to be two types of hotswap sockets. One is called [Kailh](https://jlcpcb.com/partdetail/Kailh-CPG151101S111/C5184526) and the other is called [Gateron](https://www.gateron.com/products/gateron-hot-swap-pcb-socket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). Both seem good for what they do but after a couple of quick searches it seems that Kailh is so incredibly widely used that pcb manufacturers actually stock it directly, so we will go with that.

Another important thing to consider is how to orient the switches. Here is the [datasheet](https://cherry.saas.contentserv.com/admin/rest/document/56?ContextIDs=30118&Language=36) of the switch I find most appealing. It is a terrible datasheet. Anyway, [this discussion](https://geekhack.org/index.php?topic=72713.0) basically lands on the fact that the LED orientation won't matter. I would like it to be top facing because even though I am not wiring them, it creates more space for the USB-C connector on the top.

## Diodes

I just realized I didn't set up anything at all! Let's figure it out. The overwhelming majority of people on [reddit](https://www.reddit.com/r/MechanicalKeyboards/comments/6oyxqt/which_diodes_can_i_use_help/) swear by [1N4148](https://www.vishay.com/docs/86455/1n4148ws.pdf) so why meddle with perfection. That said we might have to change the package based on the outline lead time and availability, but we'll see.

## USB-C 

For USB-C we can go with a nice terminal that isn't too crazy. Turns out [this](https://jlcpcb.com/partdetail/Korean_HropartsElec-TYPE_C_31_M12/C165948) is a commonly used one. 

It would be nice to place the microcontroller further away from the USB-C port, but for that we need to know what the best practices are for designing long USB-C trails. The [hardware design guideline](https://www.allpcb.com/blog/pcb-assembly/usb-c-connectors.html) can be helpful in that.

## Capacitors & Resistors

One main thing here is footprint. I would like the smallest possible footprint in order to place them close to the microcotroller and other components. 

For the resistor power rating we don't need much, so something around 60-100 mW should be waaaay more than enough.

1. 1k [CRCW04021K00FKED](https://jlcpcb.com/partdetail/VishayIntertech-CRCW04021K00FKED/C71623)
2. 5.1k [CRCW04025K10JNED](https://jlcpcb.com/partdetail/VishayIntertech-CRCW04025K10JNED/C482289)
3. 10k [CRCW040210K0FKEDC](https://jlcpcb.com/partdetail/VishayIntertech-CRCW040210K0FKEDC/C844714)
4. 27 [CRCW040227R0FKED](https://jlcpcb.com/partdetail/VishayIntertech-CRCW040227R0FKED/C482122)

I also found budget options for JLC's maufacturing

1. 1k [0402WGF1001TCE](https://jlcpcb.com/partdetail/12256-0402WGF1001TCE/C11702)
2. 5.1k [0402WGF5101TCE](https://jlcpcb.com/partdetail/26648-0402WGF5101TCE/C25905)
3. 10k [0402WGF1002TCE](https://jlcpcb.com/partdetail/26487-0402WGF1002TCE/C25744)
3. 33 (it needs to be between 27 and 44) [0402WGF330JTCE](https://jlcpcb.com/partdetail/25848-0402WGF330JTCE/C25105)

For the capacitors I want to also pick 0402 packaging here are the ones I found

1. 100n [0402B104J160CT](https://jlcpcb.com/partdetail/Walsin_TechCorp-0402B104J160CT/C387940)
2. 15p [GRM1555C1H150FA01D](https://jlcpcb.com/partdetail/172911-GRM1555C1H150FA01D/C161530)
3. 1u [GRM155Z71A105KE01D](https://jlcpcb.com/partdetail/548880-GRM155Z71A105KE01D/C528974)

the budget options are

1. 100n [CL05B104KO5NNNC](https://jlcpcb.com/partdetail/1877-CL05B104KO5NNNC/C1525)
2. 15p [0402CG150J500NT](https://jlcpcb.com/partdetail/1900-0402CG150J500NT/C1548)
3. 1u [CL05A105KA5NQNC](https://jlcpcb.com/partdetail/53938-CL05A105KA5NQNC/C52923)
4. 10u [CL10A106MA8NRNC](https://jlcpcb.com/partdetail/97651-CL10A106MA8NRNC/C96446)

## PCB Pushbuttons 

We need some cool buttons to reset and program! I honestly want something that feels cool and premium. Unironically this [Ebay Seller](https://www.ebay.com/itm/335354104894) is showing them off. Though these may be too big.

## Dimensions and such

Another place where I got inspiration from was the [latest planck pcb](https://imgur.com/a/planck-pcb-rev-6-8gn3UQs) mostly to know how close I can really place the components to the margins of the board before having issues.

## Daughter Board

I have been thinking a lot about using a daughter board so that I create a gasket mount keyboard. This effectively means that the ESD protection circuit is going to be on a separate board that will be connected through some kind of connector to the main one. There is a [standard](https://unified-daughterboard.github.io/#/?id=unified-daughterboard) for designing these. One thing we need to figure out is a connector. 

For the connector we can pick [this one](https://www.tti.com/content/ttiinc/en/apps/part-detail.html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) which is low profile and admitted by the standard we were talking about. 

In fact I think I will just fork the universal repo and see.

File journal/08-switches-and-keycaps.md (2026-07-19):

# Switches and Keycaps

I've left the best for last. People spend an enormous amount of time fiddling with these. So far the design allows for a wide variety of keycaps and switches. The only requirements are the MX-compatible footprints for the switchs. So let's find some. [This reddit thread](https://www.reddit.com/r/MechanicalKeyboards/comments/dzamyl/40s_keycaps_where_to_begin/) has some cool starting points. 

A nice keycap type is called PBS and its creator has a [blog post](https://kbd.news/Designing-Keycaps-for-Fun-and-Profit-1775.html) that explains how to make them. It is using an open source python based cad library called [cadquery](https://github.com/CadQuery/cadquery) and another open source keycap library called [OPK](https://github.com/cubiq/OPK). Playing around over there I found out that something along the 10-12 mm height for my keycaps is more than enough. And honestly 12mm is pushing it.

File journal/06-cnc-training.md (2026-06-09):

# CNC Training

To buld this case I need to get trained on how to use a Tormach CNC machine! So here are some notes I needed for all that.

## Vocabulary

1. Stock: The block
2. Part: The part (lol)
3. Tool path: The instructions to cut the stock into a part.
4. G-code: The programming language for toolpaths
5. Conversational: A part of the machine's software that generates G-code.

Tool types of the Tormach
1. two flute endmills
2. four flute endmills
3. edge finder
4. spot drill
5. drill bits 

Tool holders are
1. collet holder
2. set screw holder
3. drill chuck

*(Milling should not be done with drill tools)*

## Cool facts.

The tormach can machine
1. Aluminum
2. Steel
3. Wax
aka not wood

Some simple tool paths are:
1. Face 
2. Pocket 
3. Engrave (for text and stuff)
4. Drill

They have a guide book that contains a bunch of information for how to use the machine. From generating paths with conversational to safety checks and whatnot.

## Safety & SOP 
How to turn on this cool machine. 
1. Wear **safety goggles** and **NOT** gloves. 
2. Close the doors when it's spinning 
3. Check the computer and monitor are on
4. Engage emergency stop. 
5. Turn on the main switch.
6. Release the emergency stop and push the green button.
7. Click the rest button on the computer. 

How to set up a part. 
1. Starting with **z-axis** reference all the axes. 
2. There is a controller that lets you choose an axis and move it manually. 
3. Tighten the stock into the vice using parallel sets. 

Loading a tool
1. Place it in the tool holder
2. Undo the latch at the top door of the machine
3. Engage the spinde lock
4. Push the tool holder up on the tormach
5. Tighten the spindle
6. Remove the pindle lock and close the door. 

*(Sometimes when removing a tool one could require to tap the wrench on the spindle lock on top of the machine to loose the tool. Yet make sure to hold the chuck.)*

Zeroing
1. Load the edge finder
2. Move it towards the stock until it rotates slightly off center. 

The z-axis is zeroed using a drill bit. 

Cutting
1. Make sure to use coolant
2. Use the sanity checks in the back of the tormach guide to check if the cnc is set up correctly. 
3. Load the tool path

Shutting Down
1. Use G30 to push the tool all the way up
2. Engage emergency stop
3. Turn off the main power switch
4. Remove the part
5. Remove the tool and put it back
6. Vaccum the inside of the machine
7. Turn off the air compressor, and release extra stored air from it 

## Some eazy G-code commands
The settings tag on the tormach computer has a full list of commands. 
- G0: Go to 
- G30: Go to max z height

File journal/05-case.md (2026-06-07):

# Case

This actually should feed into how the PCB is designed. Trying to work out the PCB has really showed me that the position of the microcontroller is connected to where the USB port is and whatnot, so perhpas it is time to design the case and figure out at lease super basic ergonomic things. 

## Rough outline

[This open source tool](http://builder.swillkb.com) takes in the layout and designs a case and plate for it. Nothing fancy, if anything it is too simple, but it should serve as an excellent starting point to design the case around

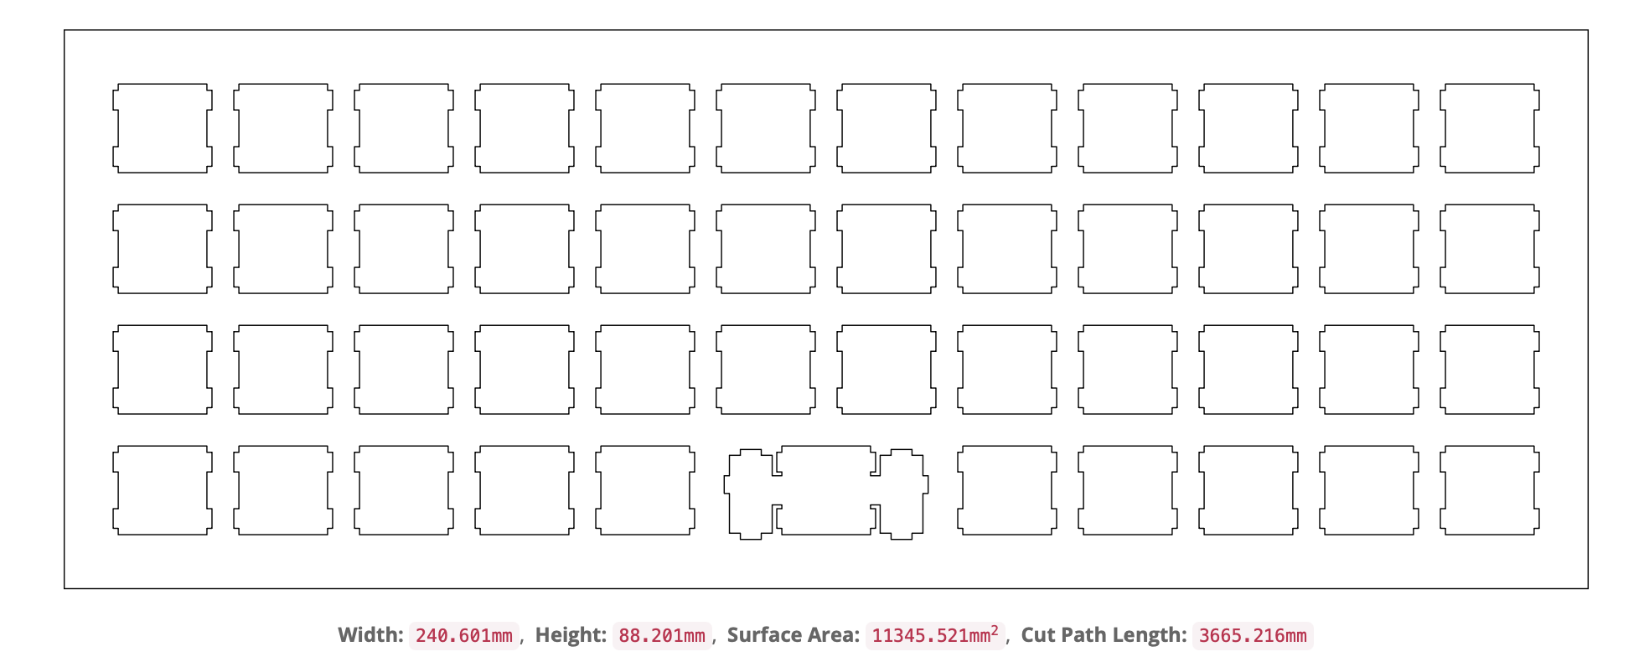
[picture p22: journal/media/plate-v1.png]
Plate starting point


That is the starting point for the plate using the layout we got, and now we are ready to come up with how to design the rest.

## CAD

I am using FreeCAD which is a surprisingly feature rich open source CAD software. In terms of inspiration this is the repo of the [olkb](https://github.com/olkb/olkb_parts) cad designs. They used to make a keyboard with the Planck layout which I loved! It was so minimal and cute, and we can use them as inspiration to understand how to make the case sturdy. 

After looking at it for sometimes the main plan seems to be as follows.

1. Anodized aluminum bottom 1.5 mm or 3 mm thickness.
2. Aluminum top plate that fits inside the bottom part. 
3. Countersunk screws from the bottom that go through the PCB and top plate.
4. Conducitve spacers for between bottom plate and PCB with nuts on top.

The thing that I am worried about is that it might sound really lound and my office mates might go crazy. So it may be worth it to add a layer of foam between the bottom plate and the pcb, or make the top plate out of some acrylic or other plastic, but this is something to figure out after the design. 

The only material I would need to figure out now-ish is the case material since the thicknelss depends on it. 

## Gasket Mount 

Turns out that my dreams for a cool silent keyboard would be impossible if I were to use that strategy. People say that mounting directly to the bottom plate creates a cavity that amplifies the sound considerably. Apparently a good way to do solve this issue is to avoid screws all together and use [gasket mounting](https://geekhack.org/index.php?topic=101731.0).

I created a design (without even a USB port) but at least this is an interation in the right direction
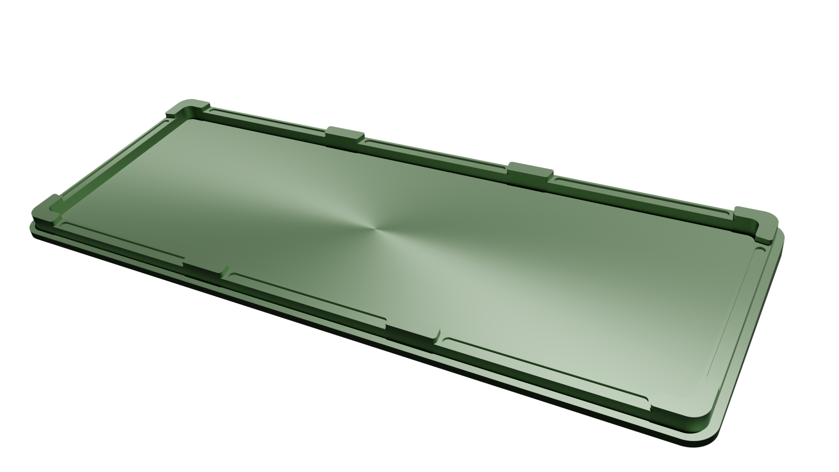
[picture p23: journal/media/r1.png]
Gasket V1

By the way this was rendered in Blender.

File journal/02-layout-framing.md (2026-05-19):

# Giving thought to the layout

Clearly first ideas suck. Not to be deterred though, we can do better! Time to give some more thought to how to design the planck layout that actually works for my workflow. So here are some modes

1. **Base**: Some version of standard qwerty. I want the stuff I know to be easily transferred there. The only question is what happens to the '" key. I have really only learned how to use it for typing "n't"and for the rest I have to really slow down and turn on my non muscle memory to type it. Shift and enter can share a spot since I only use shift in combination with other keys. We can have enter hit on release and if I chain it with any other key then it acts as shift. Another consideration would be weather to include the \ key directly in or have it in a mod layer
2. **Number**: Numbers in the home row sounds fun but I have to think about how I use them for things like motions in vim. I would often have to switch between letters and numbers so they need to be readily accessible.  
3. **Symbol**: A layer for all the sumbol keys perhaps including \ where ' is so that I can access it quickly. But this should have all the brackets accessible and whatnot, so perhaps it would be nice to have them in the home row just as well as operations. The symbol and number layers might be chained often so it would be nice to have them activated by different hands. 
4. **Navigation**: HJKL are swapped with arrows, perhaps add page up and down and whatnot there. I am not sure if that layer should be able to be activeted by both hands. Some non-vim text editors really rely on being able to do C+-> or other things so having more accessible options might be better. 
5. **Function**: Brings back function keys. Perhaps F keys on the home row, and their corresponding function keys on the one above like volume brightness and whatnot. 

## Base

One interesting layout for the base would be [this](https://www.keyboard-layout-editor.com/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'%20%22%3B&@_c=%23878787%3B&=Shift%0A%0A%0A%0AShift&_c=%23b8b8b8%3B&=Z&=X&=C&=V&=B&=N&=M&=,&=.&=%2F%2F%20%3F&_c=%23878787%3B&=Return%0A%0A%0A%0AShift%3B&@_c=%238f6dc7%3B&=Fn&_c=%23878787%3B&=Ctrl&=Alt&=Super&_c=%2386c1d1&n:true%3B&=Num&_c=%23878787&w:2%3B&=&_c=%23bfa36b&n:true%3B&=Symb&_c=%2379b56d%3B&=Nav&_c=%23878787%3B&=&=&=). 

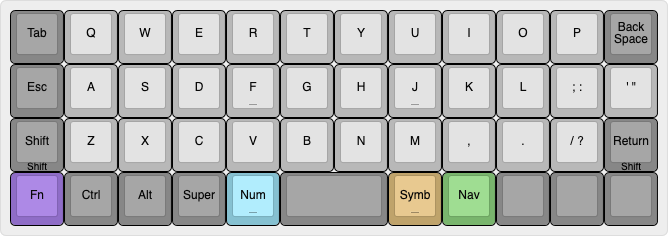
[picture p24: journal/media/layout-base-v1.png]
Base layout


The modes are highlighted with different colors, and the bottom part really means that if you long press you get shift. 
It has kept the qwerty keys as they are, has home row escape which I LOVE, and the placement of the num and symb keys with homing bumps so that I always know if I am pressing these, or the nav section. Symb is going to be used a lot when typing latex and stuff so I want it at areally natural place.  

## Number

How about [this](https://www.keyboard-layout-editor.com/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,&=.&=%2F%2F&_c=%23878787&g:true%3B&=Return%0A%0A%0A%0AShift%3B&@_c=%238f6dc7%3B&=Fn&_c=%23878787%3B&=Ctrl&=Alt&=Super&_c=%2386c1d1&n:true%3B&=Num&_c=%233998ad&g:false&w:2%3B&=Super&_c=%23bfa36b&g:true&n:true%3B&=Symb&_c=%2379b56d%3B&=Nav&_c=%23878787%3B&=&=&=).

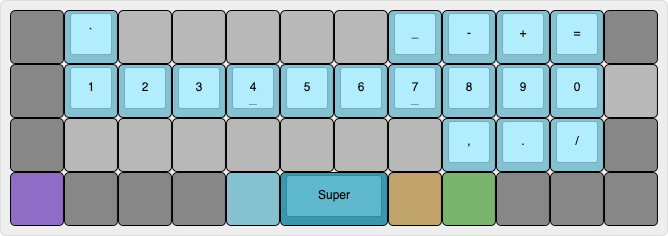
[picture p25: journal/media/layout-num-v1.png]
Number layout


It has the operations all stacked out. I found out that I use ,. and / quite often when I am typing numbers, so perhaps it would be nice to keep these when the number mod key is pressed just in case.
There areoeprations on the top that are clearly separated and I like the underscore above J it sounds like it's going to be convenient. 
One more thing is that I have a lot of SUPER + NUMBER keys on my monitor setup so I think the most accessible way to have the super key is to press it with another thumb so I put it where space is, since I won't have to touch it that often anyway. I think this is a good solution for now. Other modes can share the space key to be the super key. 

## Symbol

I think [this](https://www.keyboard-layout-editor.com/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,&=.&=%2F%2F%20%3F&_c=%23878787%3B&=Return%0A%0A%0A%0AShift%3B&@_c=%238f6dc7%3B&=Fn&_c=%23878787%3B&=Ctrl&=Alt&=Super&_c=%2386c1d1&n:true%3B&=Num&_c=%23b58b3e&g:false&w:2%3B&=Super&_c=%23bfa36b&g:true&n:true%3B&=Symb&_c=%2379b56d%3B&=Nav&_c=%23878787%3B&=&=&=) will do.

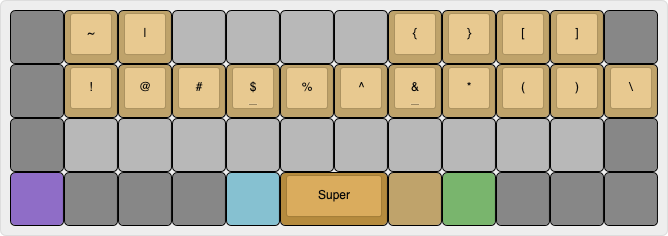
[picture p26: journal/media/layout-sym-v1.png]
Symbol Layout


It has all the mod keys in the qwerty order but brings the \ character in a more accessible place as well as the parentheses and stuff in a nicely wrapped place. 
It also has the same super key thing bound at the spacebar for easy access.

## Navigation

I got [this](https://www.keyboard-layout-editor.com/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'%20%22%3B&@_c=%23878787%3B&=Shift%0A%0A%0A%0AShift&_c=%23b8b8b8%3B&=Z&=X&=C&=V&=B&=N&=M&=,&=.&=%2F%2F%20%3F&_c=%23878787%3B&=Return%0A%0A%0A%0AShift%3B&@_c=%238f6dc7%3B&=Fn&_c=%23878787%3B&=Ctrl&=Alt&=Super&_c=%2386c1d1&n:true%3B&=Num&_c=%23548749&g:false&w:2%3B&=Super&_c=%23bfa36b&g:true&n:true%3B&=Symb&_c=%2379b56d%3B&=Nav&_c=%23878787%3B&=&=&=).

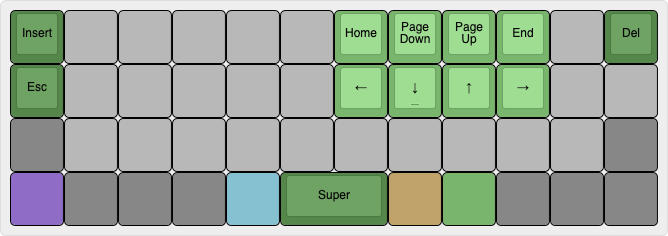
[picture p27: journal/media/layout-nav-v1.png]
Navigation layout


I don't have much to say about this. It works well HJKL move the arrows and above them are the big cousiins. Delete replaces backspace just in case, escae remains in that mode, also just in case, and tab has been swapped with insert which I really like.
Super key is still bound to spacebar because I do have a lot of keybinds for SUPER + ARROW.

## Function

And finally [here](https://www.keyboard-layout-editor.com/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'fa%20fa-volume-off'%3E%3C%2F%2Fi%3E&=%3Ci%20class%2F='fa%20fa-volume-down'%3E%3C%2F%2Fi%3E&=%3Ci%20class%2F='fa%20fa-volume-up'%3E%3C%2F%2Fi%3E&_c=%23b8b8b8&g:true%3B&=Pause&_c=%23634796&g:false%3B&=%3Ci%20class%2F='fa%20fa-power-off'%3E%3C%2F%2Fi%3E%3B&@_c=%23878787&g:true%3B&=Esc&_c=%238f6dc7&g:false%3B&=F1&=F2&=F3&_n:true%3B&=F4&=F5&=F6&_n:true%3B&=F7&=F8&=F9&=F10&_c=%23b8b8b8&g:true%3B&='%20%22%3B&@_c=%23878787%3B&=Shift%0A%0A%0A%0AShift&_c=%238f6dc7&g:false%3B&=Bright%20Up&=Bright%20Down&_c=%23b8b8b8&g:true%3B&=C&=V&=B&=N&_c=%238f6dc7&g:false%3B&=%3Ci%20class%2F='fa%20fa-backward'%3E%3C%2F%2Fi%3E&=Play%20Pause&=%3Ci%20class%2F='fa%20fa-forward'%3E%3C%2F%2Fi%3E&_c=%23b8b8b8&g:true%3B&=F12&_c=%23878787%3B&=Return%0A%0A%0A%0AShift%3B&@_c=%238f6dc7%3B&=Fn&_c=%23878787%3B&=Ctrl&=Alt&=Super&_c=%2386c1d1&n:true%3B&=Num&_c=%23634796&g:false&w:2%3B&=Super&_c=%23bfa36b&g:true&n:true%3B&=Symb&_c=%2379b56d%3B&=Nav&_c=%23878787%3B&=&=&=) we are!

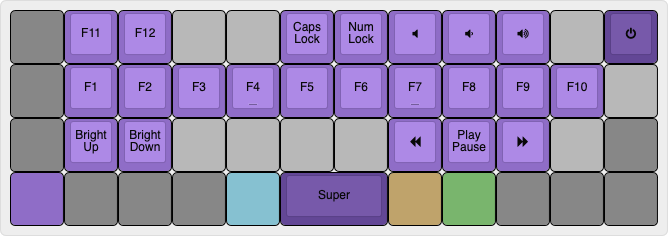
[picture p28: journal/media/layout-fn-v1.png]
Function Layout


Functions are where the corresponding numbers were except from F11 and F12. I added caps lock and num lock, which num lock should really just lock the number mode. A power button for sleeping or snoozing and some brightness and volume controls. Super key is still there because I can now do SUPER+F1 which unlocks so many possibilitites. 

## Final thoughts. 

All these are are nice. In particular I am interested in figuring out if this solves the issues that we found in the [previous journal](./01-layout-first-steps.md). It has right shift now, convenient \ for latex, themeing and hopefully I can get used to the return key being there. Also SUPER+non ALpha combinations now work well so we are good to go! (in theory.)

> I am curious if I can experiement with SPACE being SUPER when held down. I am trying to think what use case I have for holding space down, and I don't think that I have any. So it would be nice to experiment with that in the future.

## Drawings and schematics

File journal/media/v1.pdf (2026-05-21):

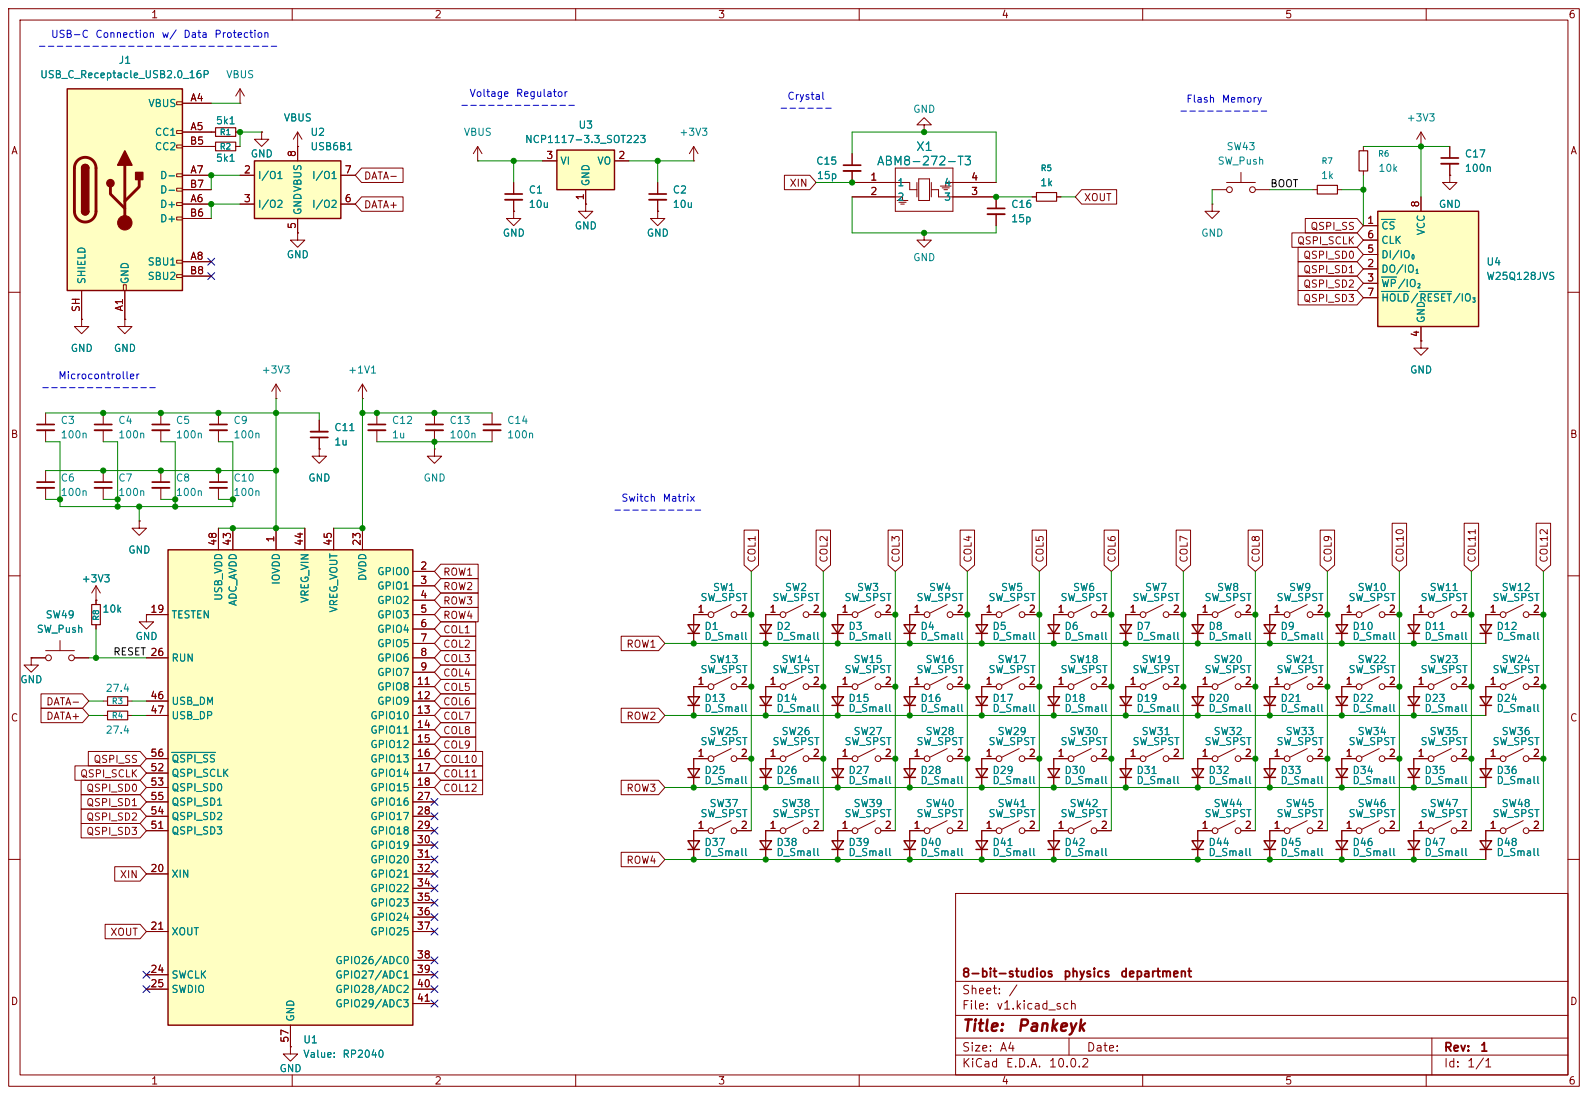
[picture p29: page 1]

4 DI/IO0 5 CLK 6 HOLD/RESET/IO3 7 VCC

Size: A4 | Rev: 1
KiCad E.D.A. 10.0.2 | Id: 1/1

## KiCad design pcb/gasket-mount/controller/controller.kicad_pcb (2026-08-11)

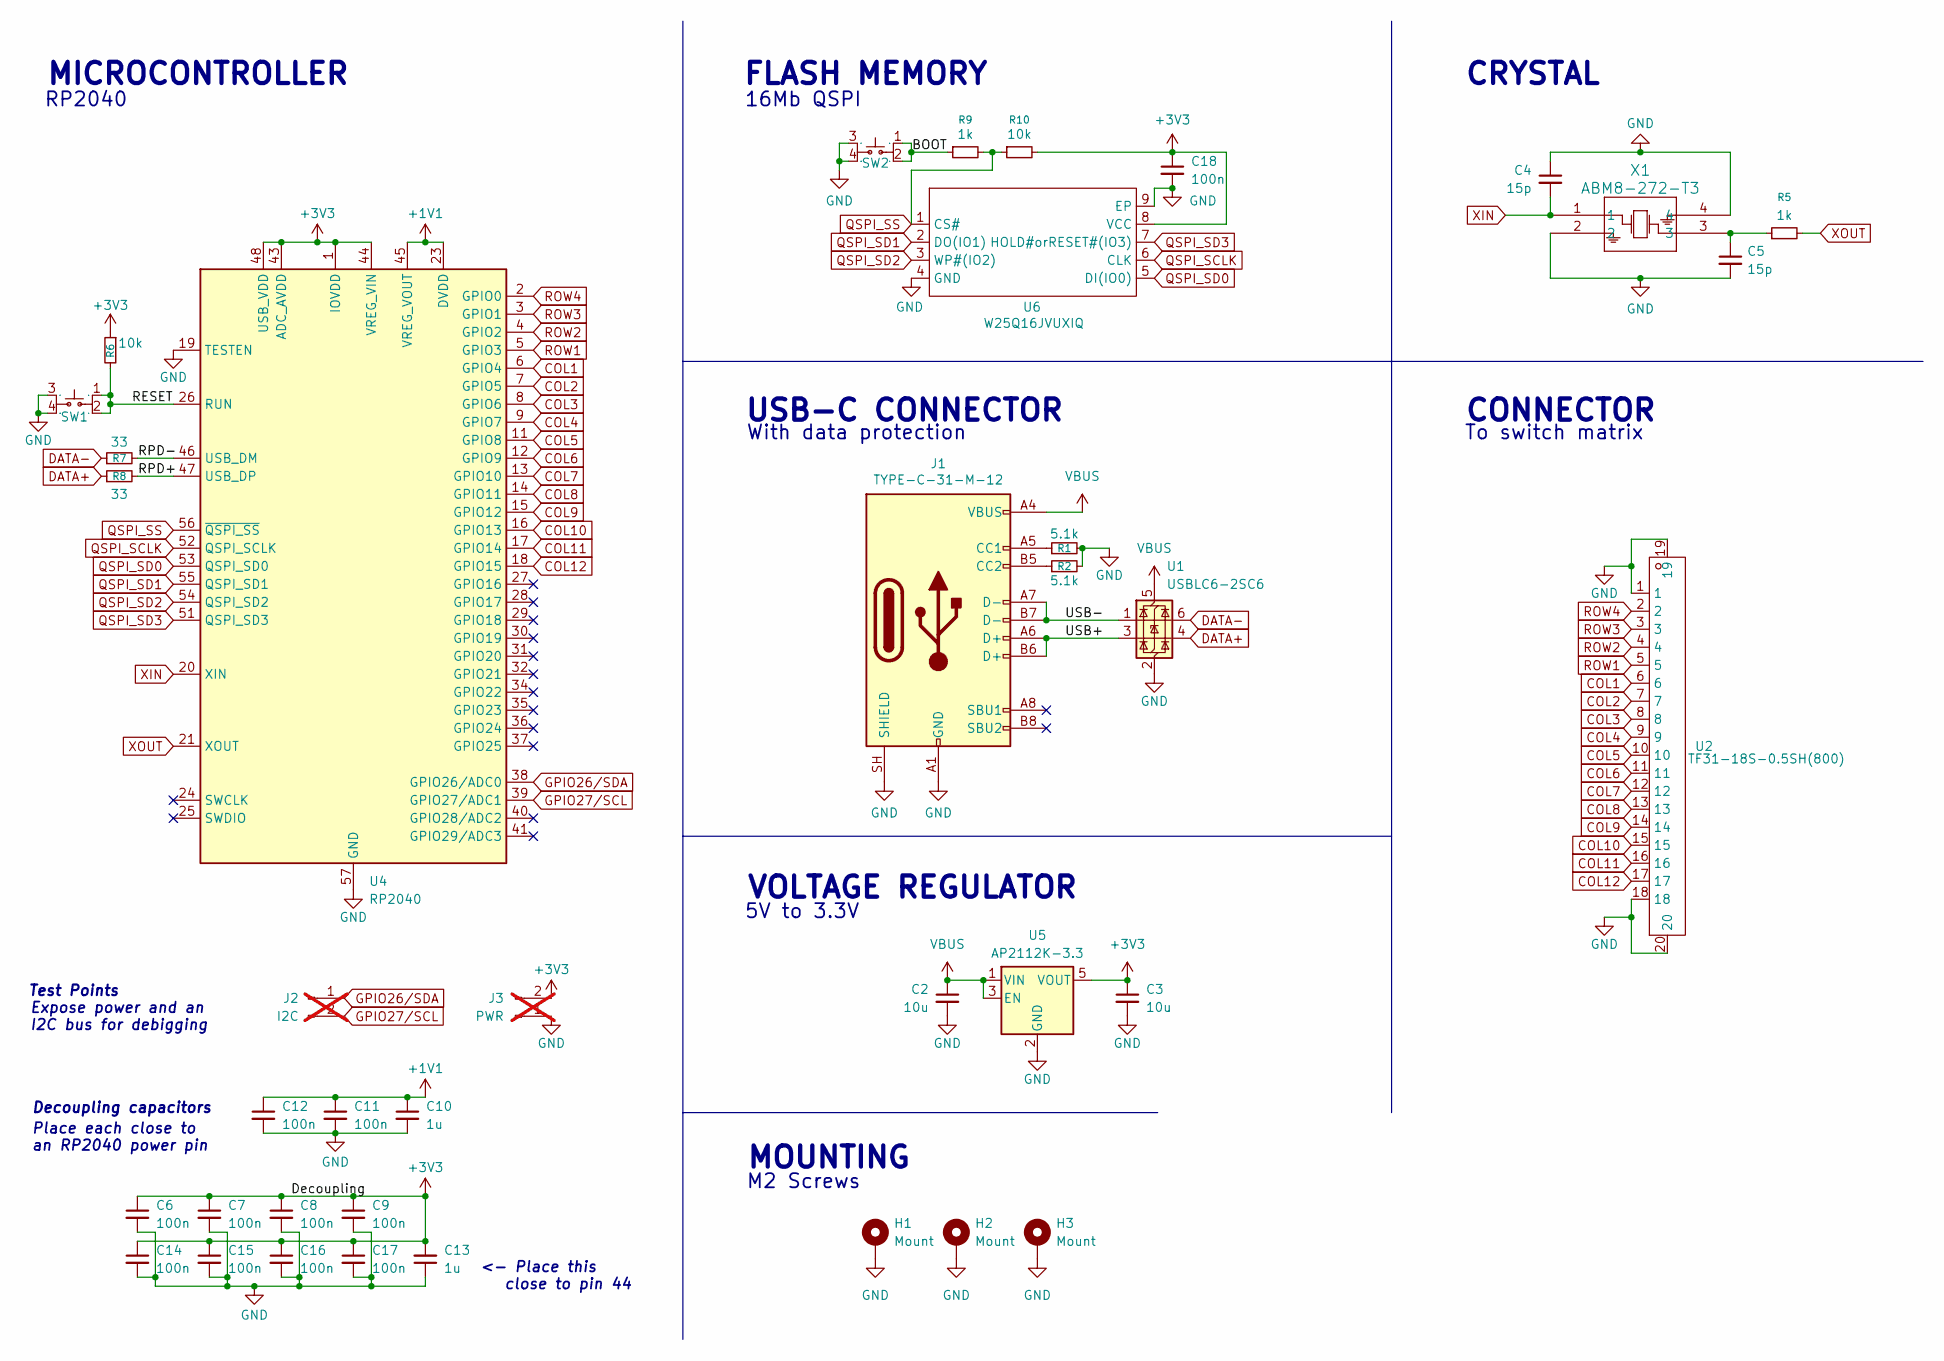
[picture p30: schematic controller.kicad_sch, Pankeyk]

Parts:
C2, C3: 10u; C_0603_1608Metric; LCSC C96446
C4, C5: 15p; C_0402_1005Metric; LCSC C1548
C6, C7, C8, C9, C11, C12, C14, C15, C16, C17, C18: 100n; C_0402_1005Metric; LCSC C1525
C10, C13: 1u; C_0402_1005Metric; LCSC C52923
H1, H2, H3: Mount; MountingHole_2.2mm_M2_ISO14580_Pad
J1: TYPE-C-31-M-12; USB_C_Receptacle_HRO_TYPE-C-31-M-12; LCSC TYPE-C-31-M-12
J2: I2C; PinHeader_1x02_P2.54mm_Vertical; not fitted
J3: PWR; PinHeader_1x02_P2.54mm_Vertical; not fitted
R1, R2: 5.1k; R_0402_1005Metric; LCSC C25905
R5, R9: 1k; R_0402_1005Metric; LCSC C11702
R6, R10: 10k; R_0402_1005Metric; LCSC C25744
R7, R8: 33; R_0402_1005Metric; LCSC C25105
SW1, SW2: SKRPAME010; KEY-SMD_4P-L4.2-W3.2-P2.20-LS4.6; Manufacturer Part SKRPAME010; LCSC C19724063
U1: USBLC6-2SC6; SOT-23-6; LCSC USBLC6-2SC6
U2: TF31-18S-0.5SH(800); FPC-SMD_18P-P0.50_TF31-18S-0.5SH-800; Manufacturer Part TF31-18S-0.5SH(800); LCSC Part Name 间距:0.5mm P数:18P 翻盖式 下接
U4: RP2040; QFN-56-1EP_7x7mm_P0.4mm_EP3.2x3.2mm; LCSC RP2040
U5: AP2112K-3.3; SOT-23-5; LCSC AP2112K-3.3
U6: W25Q16JVUXIQ; USON-8_L3.0-W2.0-P0.50-BL-EP; Manufacturer Part W25Q16JVUXIQ; LCSC C2843335
X1: ABM8-272-T3; Crystal_SMD_Abracon_ABM8G-4Pin_3.2x2.5mm; LCSC ABM8-272-T3

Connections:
+1V1: C10.1, C11.1, C12.1, U4.23 (DVDD), U4.45 (VREG_VOUT), U4.50 (DVDD)
+3V3: C3.1, C6.1, C7.1, C8.1, C9.1, C13.2, C14.1, C15.1, C16.1, C17.1, C18.1, J3.2, R6.1, R10.2, U4.1 (IOVDD), U4.10 (IOVDD), U4.22 (IOVDD), U4.33 (IOVDD), U4.42 (IOVDD), U4.43 (ADC_AVDD), U4.44 (VREG_VIN), U4.48 (USB_VDD), U4.49 (IOVDD), U5.5 (VOUT), U6.8 (VCC)
/BOOT: R9.1, SW2.1, SW2.2
/RESET: R6.2, SW1.1, SW1.2, U4.26 (RUN)
/RPD+: R8.2, U4.47 (USB_DP)
/RPD-: R7.2, U4.46 (USB_DM)
/USB+: J1.A6 (D+), J1.B6 (D+), U1.3 (I/O2)
/USB-: J1.A7 (D-), J1.B7 (D-), U1.1 (I/O1)
COL1: U2.6, U4.6 (GPIO4)
COL2: U2.7, U4.7 (GPIO5)
COL3: U2.8, U4.8 (GPIO6)
COL4: U2.9, U4.9 (GPIO7)
COL5: U2.10, U4.11 (GPIO8)
COL6: U2.11, U4.12 (GPIO9)
COL7: U2.12, U4.13 (GPIO10)
COL8: U2.13, U4.14 (GPIO11)
COL9: U2.14, U4.15 (GPIO12)
COL10: U2.15, U4.16 (GPIO13)
COL11: U2.16, U4.17 (GPIO14)
COL12: U2.17, U4.18 (GPIO15)
DATA+: R8.1, U1.4 (I/O2)
DATA-: R7.1, U1.6 (I/O1)
GND: C2.2, C3.2, C4.1, C5.2, C6.2, C7.2, C8.2, C9.2, C10.2, C11.2, C12.2, C13.1, C14.2, C15.2, C16.2, C17.2, C18.2, H1.1 (1_1), H2.1 (1_1), H3.1 (1_1), J1.A1 (GND), J1.A12 (GND), J1.B1 (GND), J1.B12 (GND), J1.SH (SHIELD), J3.1, R1.2, R2.2, SW1.3, SW1.4, SW2.3, SW2.4, U1.2 (GND), U2.1, U2.18, U2.19, U2.20, U4.19 (TESTEN), U4.57 (GND), U5.2 (GND), U6.4 (GND), U6.9 (EP), X1.2, X1.4
GPIO26/SDA: J2.1, U4.38 (GPIO26/ADC0)
GPIO27/SCL: J2.2, U4.39 (GPIO27/ADC1)
unnamed: C5.1, R5.1, X1.3
unnamed: J1.A5 (CC1), R1.1
unnamed: J1.B5 (CC2), R2.1
QSPI_SCLK: U4.52 (QSPI_SCLK), U6.6 (CLK)
QSPI_SD0: U4.53 (QSPI_SD0), U6.5 (DI(IO0))
QSPI_SD1: U4.55 (QSPI_SD1), U6.2 (DO(IO1))
QSPI_SD2: U4.54 (QSPI_SD2), U6.3 (WP#(IO2))
QSPI_SD3: U4.51 (QSPI_SD3), U6.7 (HOLD#orRESET#(IO3))
QSPI_SS: R9.2, R10.1, U4.56 (~QSPI_SS), U6.1 (CS#)
ROW1: U2.5, U4.5 (GPIO3)
ROW2: U2.4, U4.4 (GPIO2)
ROW3: U2.3, U4.3 (GPIO1)
ROW4: U2.2, U4.2 (GPIO0)
VBUS: C2.1, J1.A4 (VBUS), J1.A9 (VBUS), J1.B4 (VBUS), J1.B9 (VBUS), U1.5 (VBUS), U5.1 (VIN), U5.3 (EN)
XIN: C4.2, U4.20 (XIN), X1.1
XOUT: R5.2, U4.21 (XOUT)

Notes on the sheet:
USB-C CONNECTOR
RP2040
CONNECTOR
Decoupling capacitors
With data protection
MOUNTING
Place each close to an RP2040 power pin
M2 Screws
<- Place this close to pin 44
Expose power and an I2C bus for debigging
MICROCONTROLLER
16Mb QSPI
CRYSTAL
VOLTAGE REGULATOR
5V to 3.3V
FLASH MEMORY
Test Points
To switch matrix

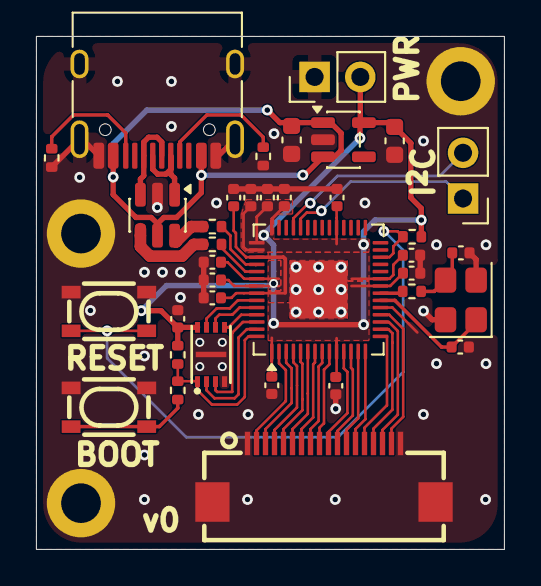
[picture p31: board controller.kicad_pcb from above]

Board: 2 copper layers, 26.0 x 28.5 mm, 39 parts (0 on the bottom side), 41 nets.

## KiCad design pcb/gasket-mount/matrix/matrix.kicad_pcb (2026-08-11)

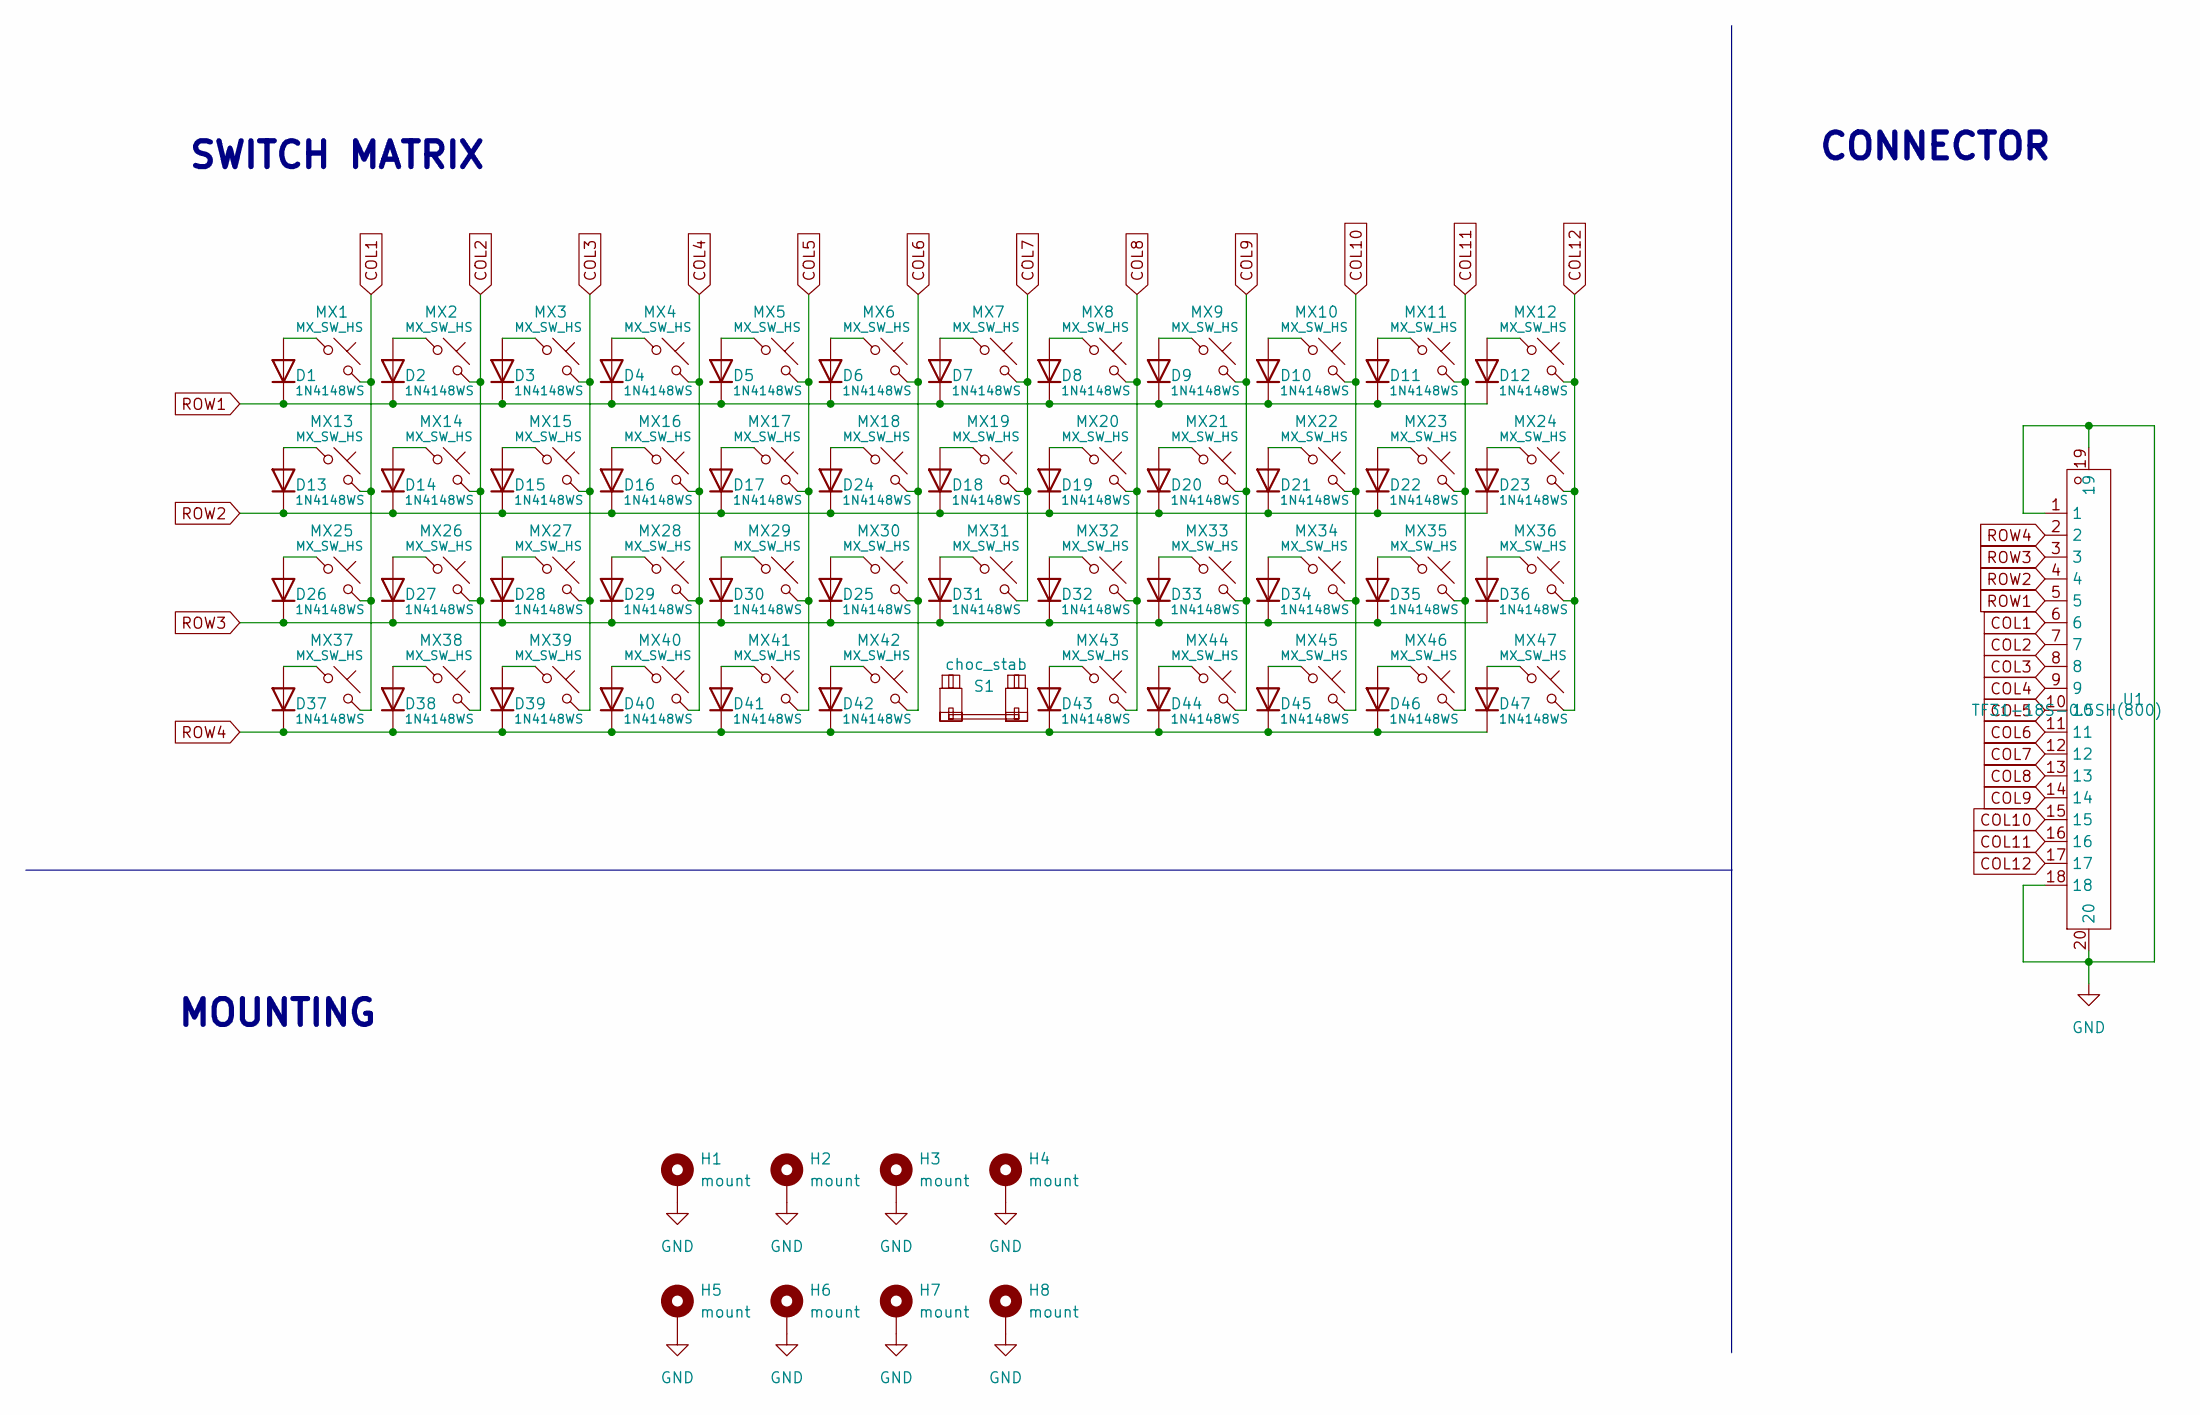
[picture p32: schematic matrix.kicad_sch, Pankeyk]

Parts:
D1, D2, D3, D4, D5, D6, D7, D8, D9, D10, D11, D12, D13, D14, D15, D16, D17, D18, D19, D20, D21, D22, D23, D24, D25, D26, D27, D28, D29, D30, D31, D32, D33, D34, D35, D36, D37, D38, D39, D40, D41, D42, D43, D44, D45, D46, D47: 1N4148WS; D_SOD-323; LCSC 1N4148WS
H1, H2, H3, H4, H5, H6, H7, H8: mount; MountingHole_2.2mm_M2_Pad_TopBottom
MX1, MX2, MX3, MX4, MX5, MX6, MX7, MX8, MX9, MX10, MX11, MX12, MX13, MX14, MX15, MX16, MX17, MX18, MX19, MX20, MX21, MX22, MX23, MX24, MX25, MX26, MX27, MX28, MX29, MX30, MX31, MX32, MX33, MX34, MX35, MX36, MX37, MX38, MX39, MX40, MX41, MX42, MX43, MX44, MX45, MX46, MX47: MX_SW_HS; SW_MX_HS_CPG151101S11_1u; LCSC CPG151101S11-2
S1: choc_stab; STAB_choc_2u
U1: TF31-18S-0.5SH(800); FPC-SMD_18P-P0.50_TF31-18S-0.5SH-800; Manufacturer Part TF31-18S-0.5SH(800); LCSC Part Name 间距:0.5mm P数:18P 翻盖式 下接

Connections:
COL1: MX1.2, MX13.2, MX25.2, MX37.2, U1.6
COL2: MX2.2, MX14.2, MX26.2, MX38.2, U1.7
COL3: MX3.2, MX15.2, MX27.2, MX39.2, U1.8
COL4: MX4.2, MX16.2, MX28.2, MX40.2, U1.9
COL5: MX5.2, MX17.2, MX29.2, MX41.2, U1.10
COL6: MX6.2, MX18.2, MX30.2, MX42.2, U1.11
COL7: MX7.2, MX19.2, MX31.2, U1.12
COL8: MX8.2, MX20.2, MX32.2, MX43.2, U1.13
COL9: MX9.2, MX21.2, MX33.2, MX44.2, U1.14
COL10: MX10.2, MX22.2, MX34.2, MX45.2, U1.15
COL11: MX11.2, MX23.2, MX35.2, MX46.2, U1.16
COL12: MX12.2, MX24.2, MX36.2, MX47.2, U1.17
GND: H1.1 (1_1), H2.1 (1_1), H3.1 (1_1), H4.1 (1_1), H5.1 (1_1), H6.1 (1_1), H7.1 (1_1), H8.1 (1_1), U1.1, U1.18, U1.19, U1.20
unnamed: D1.2 (A), MX1.1
unnamed: D2.2 (A), MX2.1
unnamed: D3.2 (A), MX3.1
unnamed: D4.2 (A), MX4.1
unnamed: D5.2 (A), MX5.1
unnamed: D6.2 (A), MX6.1
unnamed: D7.2 (A), MX7.1
unnamed: D8.2 (A), MX8.1
unnamed: D9.2 (A), MX9.1
unnamed: D10.2 (A), MX10.1
unnamed: D11.2 (A), MX11.1
unnamed: D12.2 (A), MX12.1
unnamed: D13.2 (A), MX13.1
unnamed: D14.2 (A), MX14.1
unnamed: D15.2 (A), MX15.1
unnamed: D16.2 (A), MX16.1
unnamed: D17.2 (A), MX17.1
unnamed: D18.2 (A), MX19.1
unnamed: D19.2 (A), MX20.1
unnamed: D20.2 (A), MX21.1
unnamed: D21.2 (A), MX22.1
unnamed: D22.2 (A), MX23.1
unnamed: D23.2 (A), MX24.1
unnamed: D24.2 (A), MX18.1
unnamed: D25.2 (A), MX30.1
unnamed: D26.2 (A), MX25.1
unnamed: D27.2 (A), MX26.1
unnamed: D28.2 (A), MX27.1
unnamed: D29.2 (A), MX28.1
unnamed: D30.2 (A), MX29.1
unnamed: D31.2 (A), MX31.1
unnamed: D32.2 (A), MX32.1
unnamed: D33.2 (A), MX33.1
unnamed: D34.2 (A), MX34.1
unnamed: D35.2 (A), MX35.1
unnamed: D36.2 (A), MX36.1
unnamed: D37.2 (A), MX37.1
unnamed: D38.2 (A), MX38.1
unnamed: D39.2 (A), MX39.1
unnamed: D40.2 (A), MX40.1
unnamed: D41.2 (A), MX41.1
unnamed: D42.2 (A), MX42.1
unnamed: D43.2 (A), MX43.1
unnamed: D44.2 (A), MX44.1
unnamed: D45.2 (A), MX45.1
unnamed: D46.2 (A), MX46.1
unnamed: D47.2 (A), MX47.1
ROW1: D1.1 (K), D2.1 (K), D3.1 (K), D4.1 (K), D5.1 (K), D6.1 (K), D7.1 (K), D8.1 (K), D9.1 (K), D10.1 (K), D11.1 (K), D12.1 (K), U1.5
ROW2: D13.1 (K), D14.1 (K), D15.1 (K), D16.1 (K), D17.1 (K), D18.1 (K), D19.1 (K), D20.1 (K), D21.1 (K), D22.1 (K), D23.1 (K), D24.1 (K), U1.4
ROW3: D25.1 (K), D26.1 (K), D27.1 (K), D28.1 (K), D29.1 (K), D30.1 (K), D31.1 (K), D32.1 (K), D33.1 (K), D34.1 (K), D35.1 (K), D36.1 (K), U1.3
ROW4: D37.1 (K), D38.1 (K), D39.1 (K), D40.1 (K), D41.1 (K), D42.1 (K), D43.1 (K), D44.1 (K), D45.1 (K), D46.1 (K), D47.1 (K), U1.2

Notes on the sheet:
CONNECTOR
MOUNTING
SWITCH MATRIX

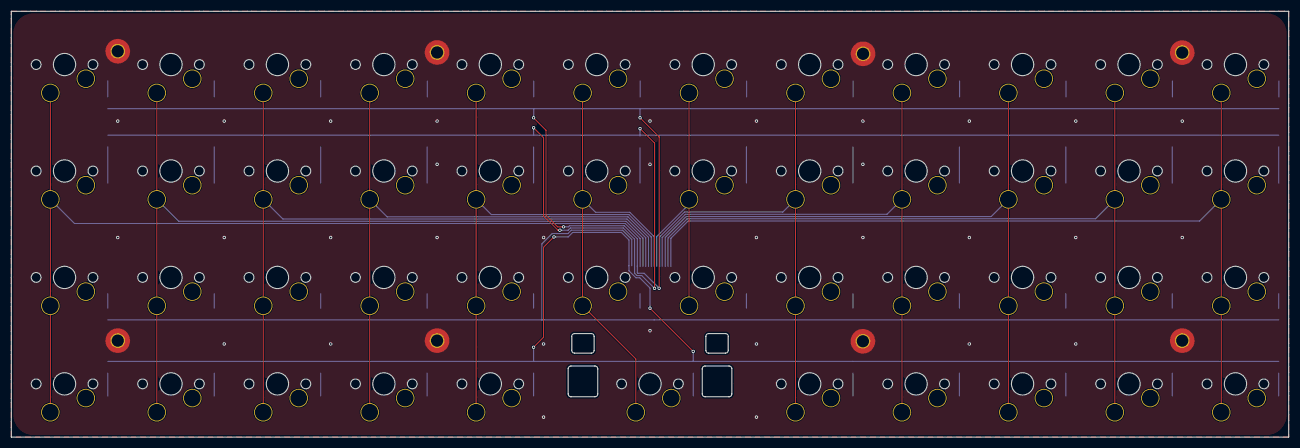
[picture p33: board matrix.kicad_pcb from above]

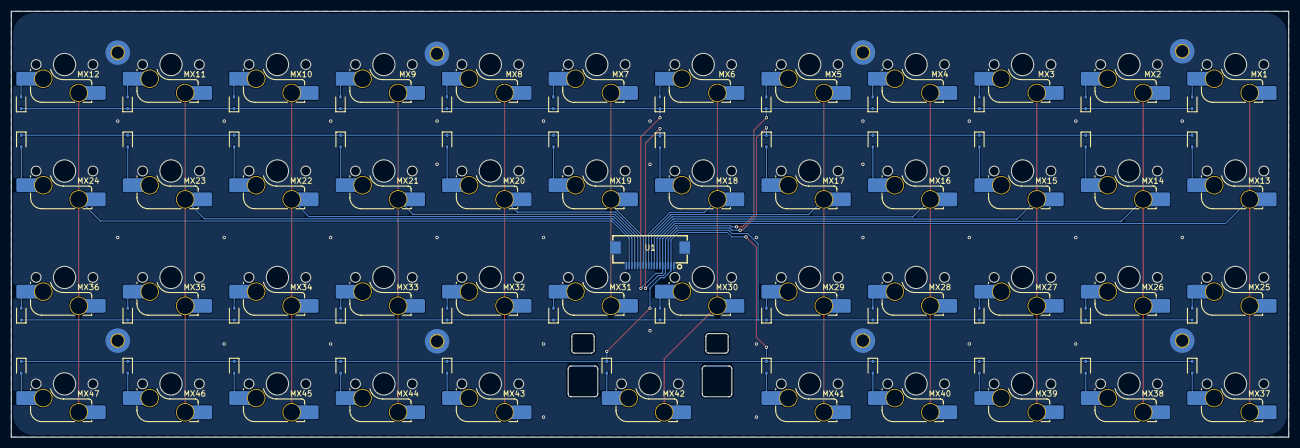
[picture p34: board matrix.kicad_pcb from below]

Board: 2 copper layers, 228.6 x 76.2 mm, 104 parts (95 on the bottom side), 64 nets.

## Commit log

2026-05-20 new schematic
    [v1.kicad_pcb, v1.kicad_sch]
2026-05-20 Squashed 'pcb/component-libraries/MX_V2/' content from commit 0b379ee
    git-subtree-dir: pcb/component-libraries/MX_V2
    git-subtree-split: 0b379eebbeb66c7fd6e82e400b47958ad695614e
    [Gateron-KS33-Socket.step, Kailh-Choc-Socket-CPG135001S30.step, MX-Hotswap-Socket.step]
2026-05-20 First pcb schematic
    [v1.kicad_sch]
2026-05-20 ignore temporary kicad files
2026-05-21 schematic version 1
    [v1.kicad_sch]
2026-05-22 centering pcb
    [v1.kicad_pcb]
2026-05-23 bottom case rev 1 and pcb updates
    [Bottom_Plate_inner_sketch.dxf, case-v1.FCStd, v1.kicad_pcb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]
2026-05-24 pcb v1
    [case-v1.FCStd, v1.kicad_pcb, v1.kicad_sch]
2026-05-25 Minor placement changes and mates
    [assembly.FCStd, board.FCStd, case-v1.FCStd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]
2026-05-29 pcb BOM updates
    [bom.csv, positions.csv, v1.kicad_pcb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]
2026-05-29 case asseembly
    [assembly.FCStd, board.FCStd, switch.FCStd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]
2026-06-02 pcb updates
    [v1.kicad_pcb]
2026-06-02 case restart for gasket
    [assembly.FCStd, board.FCStd, case-v1.FCStd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]
2026-06-07 bottom case
    [gasket-mount-keyboard.FCStd]
2026-06-07 gasket mount
    [Scene.blend, gasket-mount-keyboard.FCStd]
2026-06-08 top plate with screws
    [gasket-mount-keyboard-bottom-plate.step, gasket-mount-keyboard-top-plate.step, gasket-mount-keyboard.FCStd]
2026-06-23 ok so time to make a daughter board
    [controller.kicad_pcb, controller.kicad_sch]
2026-07-08 gasket pcb
    [controller.kicad_pcb]
2026-07-08 ignored kicad's git
2026-07-09 Netclasses and ready for updated pcb layout
    [TF31-18S-0.5SH_800_.step, controller.kicad_pcb, controller.kicad_sch]
2026-07-10 Compact form factor
    [KEY-SMD_4P-L4.2-W3.2-H2.5-LS4.6-P2.2.step, SKRPAB.STEP, controller.kicad_pcb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]
2026-07-10 Last commit before changing Flash memory
    [controller.kicad_pcb, controller.kicad_sch]
2026-07-10 new flash
    [W25Q16JVUXIQ_WIN.step, controller.kicad_pcb, controller.kicad_sch]
2026-07-11 Keyboard matrix
    [TF31-18S-0.5SH_800_.step, matrix.kicad_pcb, matrix.kicad_sch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]
2026-07-11 Fixed USB traces
    [controller.kicad_pcb]
2026-07-11 fixed switches with extra 3D models
    [matrix.kicad_pcb, switch.step]
2026-07-11 PCB finishing touches
    [Pankeyk_0_bom.csv, Pankeyk_0_designators.csv, Pankeyk_0_positions.csv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]
2026-07-12 3d model
    [controller.kicad_pcb, controller.step, gasket-mount-keyboard.FCStd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]
2026-07-12 I think it might be time for a hardware redesign
    [controller.kicad_pcb, gasket-mount-keyboard.FCStd]
2026-07-13 new gasket case design with heavy focus on master sketches
    [Scene.blend, gasket-mount-keyboard-bottom-plate.step, gasket-mount-keyboard-top-plate.step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]
2026-07-15 rebuild #2329423
    [controller.kicad_pcb, gasket-mount-v1.FCStd]
2026-07-15 it has started to keyboard
    [gasket-mount-v1.FCStd]
2026-07-16 case updates
    [gasket-mount-v1.FCStd]
2026-07-16 first complete model
    [gasket-mount-v1.FCStd]
2026-07-20 tighter tolerances
    [blenderer.blend, gasket-mount-v1-bottom.step, gasket-mount-v1-top.step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]
2026-08-11 I finally ordered\!
    [Pankeyk_0_bom.csv, Pankeyk_0_designators.csv, Pankeyk_0_positions.csv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]
